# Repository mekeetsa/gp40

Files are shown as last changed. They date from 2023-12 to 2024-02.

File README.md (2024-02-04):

# Galaksija 40th Anniversary Tribute

This Galaksija Plus mod is based on PVV's clone from 2017
with the following modifications:

- USB HID keyboard/mouse/gamepad interface using RPI Pico
- a keyboard (optional) stackable either on the upper or the bottom side
- proper composite video output (no need to reduce the power in voltage)
- added an optional bus contention remover
- address decoder with ATF16V8B or g16v8s equivalent
  which provides a configurable MEMRQ map with 1 kB granularity
- improved SD hardware (SD now runs on the CPU clock)
- SD DOS version 8.12
- integrated micro SD socket with 3.3V PS and LVTTL level shifters
- integrated audio interface
- two I/O ports connected to the audio interface
- NMI reset circuit
- hybrid TH/SMD PCB (SMD discrete components on the bottom side)
- board dimensions 100 mm x 190 mm

## Specifications

- Z80A CPU at 3.072 MHz, 32 kB ROM (16k used), 32 kB static RAM
- Text mode 32x16 characters, monochrome
- Graphics mode: 256x208 pixels
- Storage: cassette tape (280 or 1200 bit/s) 
  MicroSD card (up to 4 GB) with SDOS
- Sound: 3 channels + white noise provided by AY-3-8910 or YM2149F
- I/O ports: two 8-bit parallel ports
- USB HID keyboard/mouse interface (as add-on)
- Power consumption: less than 250 mA at 5V 

## Firmware

- `GP40_U11_ROM.bin`, ROM 1-4, fits EPROM 27C128-27C512
- `GP40_U5_CHRGEN.bin`, character generator, fits EPROM 27C64-27C512
- `GP40_U2.jed`, address decoder, fits g16v8s
- `GP40_U40.jed`, SD interface, fits g16v8ms
- `GP40_U2.lgc` and `GP40_U40.lgc`, test vectors for XGecu Pro programmers

## Hardware memory map

```
  $0000...$0FFF  ROM A or 1: 4 kB (bootstrap and BASIC)
  $1000...$1FFF  ROM B or 2: 4 kB (math functions, etc.)
  $2000...$27FF  Keyboard and latch
  $2800...$BFFF  RAM: 30 kB ($2800...$2BFF Video RAM)
  $C000...$C7FF  RAM: 2 kB (used by SDOS)
  $C800...$CFFF  SD HWM PVV interface: 2 kB
  $D000...$DFFF  Unused, 4 kB (routed to CS on the expansion bus)
  $E000...$EFFF  ROM 3: 4 KB (Galaksija Plus, graphics)
  $F000...$FFFF  ROM 4: 4 KB (SD DOS)
```

## Credits
 
- Voja Antonic: Galaksija (1983)
- Nenad Dunjic and Milan Tadic: Galaksija Plus mod (1985)
- PVV and Fifan: Galaksija Plus clone with SD card (2016)
  http://www.nedopc.org/forum/viewtopic.php?p=87313
- Goran Stankovic (YT2FSG):  Retro Computers web page
  https://www.qsl.net/yt2fsg/galaksija/galaksija_clone.html
- Retro Bertie (@MacBerti28): YouTube guide
 
## Soldering sequence
 
  1. start with the SMD components on the bottom side
     (the SMD components are 0805+ and easy to solder)
  2. solder the SMD components on the top side
  3. solder the IC sockets
  4. solder the rest of the TH components

# Subprojects

## LTspice_composite_video

Simulations for adjustment of the composite video impedance maching
and amplification (i.e. output signal levels).

## LTspice_SD_interface

Simulations for the optimized SD interface.

## SDOS_V8C_GP40

Contains SD DOS version v8.12 that supports the optimized SD interface 
(with one g16v8ms and one 74HCT299).

## Add-ons

- Pico_USB_HID, USB HID (keyboard/mouse/gamepad) interface
- PS2_KBD, PS/2 interface
- Keyboard MX Cherry keyboard

## PCB Images

PCB release R1C and R1D

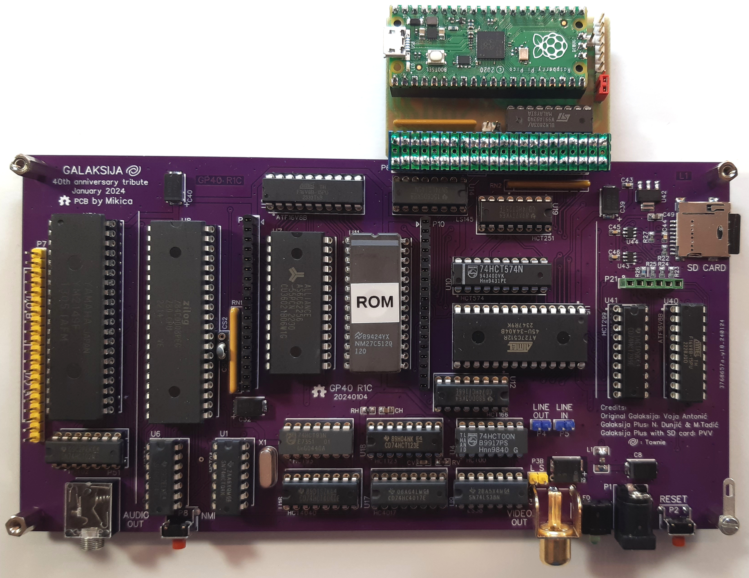
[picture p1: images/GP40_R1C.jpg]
GP40 R1C


PCB release R1A

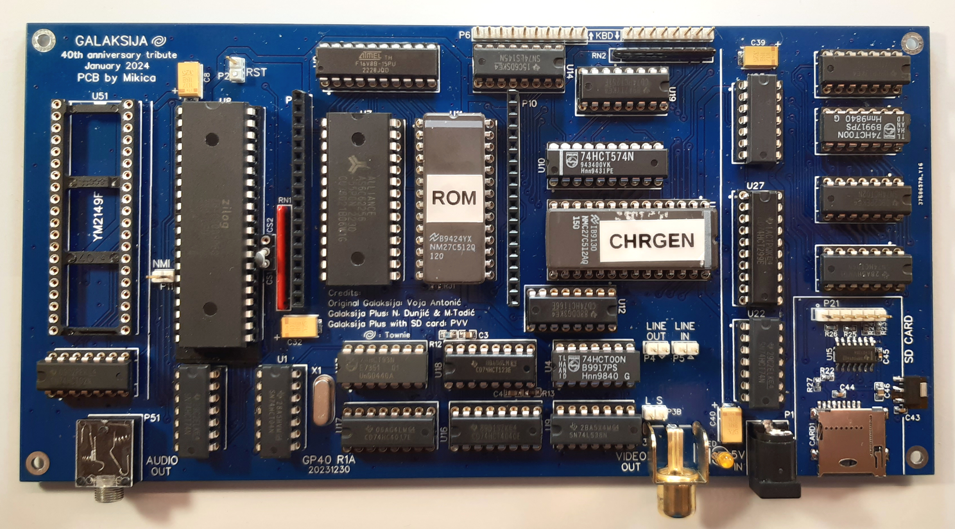
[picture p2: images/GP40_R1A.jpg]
GP40 R1A


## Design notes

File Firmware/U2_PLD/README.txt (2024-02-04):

Install WinCUPL from:

    https://www.microchip.com/en-us/products/fpgas-and-plds/spld-cplds/pld-design-resources

into:

    C:\Wincupl

The graphical interface does not work on Win 10. Use cupl.exe instead or wine under Linux.

Related Mnemonics:  g16v8, g16v8as, g16v8ma, g16v8ms, g16v8s

       Registered  Complex   Simple    Auto Mode Select
CUPL   G16V8MS     G16V8MA   G16V8AS   G16V8

In registered mode pin 1 and pin 11 are permanently configured
as clock and output enable, respectively. These pins cannot be configured
as dedicated inputs in the registered mode.

In complex mode pin 1 and pin 11 become dedicated inputs and
use the feedback paths of pin 19 and pin 12 respectively. Because
of this feedback path usage, pin 19 and pin 12 do not have the
feedback option in this mode.

In simple mode all feedback paths of the output pins are routed
via the adjacent pins. In doing so, the two inner most pins (pins
15 and 16) will not have the feedback option as these pins are
always configured as dedicated combinatorial output.

            ______________
           |    GP_U2     |
 !MREQ x---|1           20|---x Vcc  
   A15 x---|2           19|---x A14R 
   A14 x---|3           18|---x A7R  
    A7 x---|4           17|---x !RAM 
   A13 x---|5           16|---x A13R 
       x---|6           15|---x !CSE 
   A11 x---|7           14|---x !KEY 
   A12 x---|8           13|---x !ROM 
   D13 x---|9           12|---x !CSSD
   GND x---|10          11|---x      
           |______________|
           
=============================================
      !                             !        
      M                     ! ! ! ! C  A A   
      R  A A A  A A    D A  R R C K S  1 1   
      E  1 1 1  1 1  A 1 7  O A S E S  4 3   
      Q  5 4 3  2 1  7 3 R  M M E Y D  R R      
=============================================
0001: X  X X X  X X  X X X  X X X X X  X X
0002: X  X X X  X X  0 1 L  X X X X X  X X
0003: X  X X X  X X  0 0 H  X X X X X  X X
0004: X  X X X  X X  1 0 H  X X X X X  X X
0005: X  X X X  X X  1 1 H  X X X X X  X X
0006: 1  X X X  X X  X X X  H H H H H  X X
0007: 0  0 0 0  X X  X X X  L H H H H  L L
0008: 0  0 0 1  0 0  X X X  H H H L H  L H
0009: 0  0 0 1  0 1  X X X  H L H H H  L H
0010: 0  0 0 1  1 0  X X X  H L H H H  L H
0011: 0  0 0 1  1 1  X X X  H L H H H  L H
0012: 0  0 1 0  X X  X X X  H L H H H  H L
0013: 0  0 1 1  X X  X X X  H L H H H  H H
0014: 0  1 0 0  X X  X X X  H L H H H  L L
0015: 0  1 0 1  X X  X X X  H H L H H  L H
0016: 0  1 1 0  0 0  X X X  H L H H H  L H
0017: 0  1 1 0  0 1  X X X  H H H H L  L H
0018: 0  1 1 0  1 0  X X X  H H H H L  L H
0019: 0  1 1 0  1 1  X X X  H H H H L  L H
0020: 0  1 1 1  X X  X X X  L H H H H  H H

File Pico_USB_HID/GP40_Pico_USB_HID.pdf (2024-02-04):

A | A
B | B
C | C
D | D

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
### TITLE:

GALAKSIJA Pico USB HID | REV: | 1.0
Date: | 2024-01-24
Sheet: | 1/1
Drawn By: | mikica
Company: | Umuntu ngumuntu ngabuntu

+3V3

GND | GND GND

GND

GND | GND

GND

GND

RX
TX

VBUS

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
GP0-GP6 are configured as inputs. GP7-GP15 are configured as outputs.

KCs are connected to LS145. KRs are connected to LS251.

column scan

A USB HID is connected through an OTG USB cable.
The power to the HID is through J1.
Supported HIDs are keyboards and mice.

Interfacing between 3V3 and 5V TTL is done using open collectors. Adding the pull-ups will decrease speed-up low-high O.C. recovery.

RP2040 has two cores where TinyUSB runs on the first core.

The second core is dedicated to column scan / row response.
It runs a loop where the KC bits are mapped to the KR bits.
The KC/KR matrix occupies 128 bytes of memory.
The response time is max 200 ns with RP2040 running at 125 MHz. The RP2040 can be overclocked up to 400 MHz (which is not needed).

Debugging is done using SWD. Wiring setup:
- connect J2 (SWD) and J3 (UART0) to Pico probe
- if standalone, connect power to J1 pins 1-2
- if connected to Galaksija, install a jumper between J1 pins 2-3

ULN2803A

U2

1IN 1
2IN 2
3IN 3
4IN 4
5IN 5
6IN 6
7IN 7
8IN 8
GND 9 | COM 10 OUT8 11 OUT7 12 OUT6 13 OUT5 14 OUT4 15 OUT3 16 OUT2 17 OUT1 18

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
column scan

row response

2k-10k

RN1

+3V3

+3V3

HDR_1x3

J2

3

1
2

0.1u

C1
0.1u

C2

+5V

row response

GND HDR_1x3

J1
3

1

2

HDR_1x3

J3
3

1

2

GND

SWDIO

SWCLK
GND

RUN
HDR_1x1

J4
1

Note that the power on the Pico's USB connector is sourced out.

J1 usage: Normally jumper between pins 2-3 (+5V to VBUS).
If standalone (debugging), connect an external cable to pins 1-2.

column scan

VBUS

0.1u

C3

CPU_RESET
BSS138

Q1

CPU_RESET

10k

R1

CTRL-ALT-DELETE
sets \RESET to low.

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
2k-10kR2
2k-10kR3
2k-10kR4
2k-10kR5
2k-10kR6
2k-10kR7
2k-10kR8
2k-10kR9
2k-10kR10 | \RESET

Optional pull-ups 2k-10k
(to decrease turn-on/off delay time of O.C.)

\RESET

Keyboard

P6
GND 1

KC6 2
KC5 3
KC4 4
KC3 5
KC2 6
KC1 7

KC0 8 KR0 14 KR1 15 KR2 16 KR3 17 KR4 18 KR5 19 KR6 20 KR7 21

VCC 10 GND 9 GND 11 | \RST 12

N.C. 13

\RESET

RASPBERRY PI PICO
GP0 1

U1

GP1 2

GP2 4
GP3 5
GP4 6
GP5 7

GP6 9
GP7 10
GP8 11
GP9 12

GP10 14
GP11 15
GP12 16
GP13 17

GP14 19

GP15 20 | GP16 21 GP17 22

GP18 24 GP19 25 GP20 26 GP21 27

GP22 29 RUN 30 GP26 31 GP27 32

GP28 34

GND 3

GND 8

GND 13

GND 18 | GND 23

GND 28

GND 33

GND 38
ADC_VREF 35 3V3_OUT 36 3V3_EN 37

VSYS 39 VBUS 40

PWM 3

PWM 6

PWM 5

PWM 2

PWM 1

PWM 0PWM 7

PWM 6

PWM 5

PWM 4

PWM 3

PWM 2

PWM 1

# PWM 0 SWCLK 41

## GND 42

## SWDIO 43

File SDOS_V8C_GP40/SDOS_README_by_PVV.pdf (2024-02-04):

SD Card and SDOS for 8-bit Computers Author: PVV (Vitaly V. Popov, Rostov-on-Don)

Source: https://zx-pk.ru/threads/29892-sd-karta-i-sdos-dlya-8i-bitnykh-pk.html
Author: https://www.qrz.ru/db/RX6LEJ

http://www.nedopc.org/forum/viewtopic.php?id=6181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 (version 8.9J, Jupiter ACE, latest found)

The most recent version found: v8.C from 11.03.2020, 23:15 https://zx-pk.ru/attachment.php?attachmentid=71773&d=1583957695

I have a desire to organize and compile all the information about the SDOS system in one place. Honestly, I did not anticipate that SDOS would grow to its current scale, and now I sometimes face difficulty finding information about a specific build.

What is SDOS?

SDOS is a compact console shell that allows reading and executing files from an SD card formatted in FAT16. It can also write data back to the card from the computer's RAM. This makes it very easy to transfer files between 'big' PCs and our retrocomputers. The codebase of SDOS is based on the code from the respected b2m (http://bashkiria-2m.narod.ru), which I framed with additional functionality and capabilities. The system code is designed to be easily adaptable to any PC and any hardware interface and storage medium (it doesn't necessarily have to be an SD card; it can be an HDD).

SDOS properties:

- The code itself occupies from 2 to 2.5 KB (can be located in both ROM and RAM), and an additional 2 KB of RAM is required to work with FAT16.
- Has been compiled and tested at least in the emu emulator, and in some cases, in real life on the following PCs: Specialist std (real) and MX2 (real), RK-86 (real), Apogee, Partner-01, Galaksija (real), Orion (real), TRS-80 (real), YUT-88.
- Supports three basic SD hardware interfaces: HWM_PVV, msx, n8vem, and their derived variants.
- Supports SD and SDHC cards, i.e., cards larger than 4 GB.

Supports the following basic directives:

- CD DirectoryName
change to the directory with the specified name;
- DIR
display the list of files and directories;
- FileName.RKX
(RKS for std, RKR for RK-86, GTP for Galaksija, RKO for Orion, CAS for TRS-80) -execute the file; the extension can be omitted, and autocompletion will occur;
- R FileName.Extension, Address, Size
read the file without executing it, starting from the specified memory address and reading the specified number of bytes.

Example: R TEST.BIN,0ACD,5FE0 - reads the TEST.BIN file into memory starting from address 0x0ACD and ending at address 0x0ACD+0x5FE0=0x6AAD. There is no check for the actual length of the file and the requested read size, so you can request to read more than the file's size, and the behavior is undefined.

- W FileName.Extension, Address, Size
write data from memory to the file, starting from the specified address in memory and writing the specified number of bytes.

Example: W TEST.BIN,0ACD,5FE0 - writes to the TEST.BIN file from memory starting from address 0x0ACD and ending at address 0x0ACD+0x5FE0=0x6AAD. There is no check for the actual length of the file and the requested write size, so you can request to write more than the file's size, and the behavior is undefined. It is not possible to write more than the existing file size. If you write less data than the file size, the file size remains unchanged.

- X
switch to the monitor from which SDOS was launched;
- I
initiate card reinitialization.

Only for Galaksija:

- WB FileName.Extension
write BASIC program to the SD file in GTP format.

Only for SpecialistMX:

- L FileName.Extension
read the file in RKX format from SD to MX RAM disk; example: L TEST.BIN - reads the TEST.BIN file into memory starting from address 0x0000 and ending at its length address, creates a file TEST.BIN on the RAM disk with a start address and size taken from the first 4 bytes of the file on the card, assuming that the file name in the header was absent (0xE6 in the 5th byte). Or: L TEST.BIN - reads the TEST.BIN file into memory starting from address 0x0000 and ending at its length address, creates a file TEST_MX.HEX on the RAM disk with the start address and size read from the first 4 bytes of the file on the card, and the file name in the header is TEST_MX.HEX.
- S FileNameOnRAMDisk.Extension, FileNameOnSD.Extension
write the file data from RAM disk to SD in RKX format; example: S TEST.BIN - reads the TEST.BIN file from RAM disk into memory starting from address 0x0000 and ending at its length address, then writes it to the SD card in the existing file with the same name TEST.BIN, the size remains unchanged, RKX format! Or: S TEST.BIN,TEST_MX.HEX -reads the TEST_MX.HEX file into memory starting from address 0x0000 and ending at its length address, then writes it to the SD card in the existing file with the name TEST.BIN.

Only for Orion:

- L FileName.Extension
read the file in RKO format from SD to RAM disk; example: L TEST$.RKO - reads the

TEST$.RKO file into memory starting from address 0x0000 and ending at its length address, creates a file TEST$ on the RAM disk with the name, start address, and size taken from the RKO file header on the card.

- S FileNameOnRAMDisk, FileNameOnSD.Extension
write the file data from RAM disk to SD in RKO format; example: S TEST$,TEST1$.BIN -reads the TEST$ file from RAM disk into memory starting from address 0x0000 and ending at its length address, then writes it to the SD card in the existing file with the name TEST1$.BIN, the size remains unchanged, RKO format!

When listing the directory with DIR, the name, file extension, and size of the file are printed (so that you can use R and W directives), and for directories, DIR is written in the file size field.

When starting a file, the start and end addresses to which the file will be read from the card are written.

Pressing any key (or space) during DIR output pauses the file list output.

For SpecialistMX2, the ability to run not only RKX files but also RKS is implemented. To do this, in the same directory where the RKS file is located, you need to place the M2_C000.MON monitor file (taken from the Vinxru project). In addition, there is the possibility to load arbitrary monitors.

And now a lot of links, mentioning SDOS and SD interface.

It all started with this thread about Specialist with the HWM interface, and back then, I thought it would end there, but it didn't. The first attempt to organize information about SDOS within the framework of Specialist.

Version for RK-86 with HWM_PVV interface, then with RK86_WW55_SD_HWM_PVV interface, then Apogee with the original card connection option, an analog of the SD_n8vem interface. In these variants, the SD card is connected together with the ROM disk, without excluding it! Partner-01.

Version for Galaksija with HWM_PVV interface and with SD_n8vem interface.
Practical implementation in this thread.

YUT-88 with SD_n8vem interface.
Orion.
TRS-80.

Interface schematics:

HWM_PVV on IR8 and IR9 or on ports VV55. HWM_PVV on IR24 or here or here. HWM_PVV on IR13.

SD_n8vem or here or here or here.

I haven't tested SD_msx in real life, only in emulation, but initially, b2m's code was implemented to work specifically with this interface, and it was used in real life on PLD.

I want to add one more point. According to the specification, when initializing the SD card, you need to use an SD_CLK clock frequency not exceeding 400 kHz, and after initialization, switch to a higher frequency. But as practice has shown, modern cards easily initialize and work at a frequency of 2-4 MHz, allowing you to dispense with the clock speed switch. Speed switching is only supported in the HWM PLD interface and in the first version of the HWM_PVV interface on discrete components.

…

The source code for SDOS is open, and it can be downloaded from the link above.

SDOS is written in i8080 mnemonics (actually i8085) and runs on Z80 without any problems.

Each time I added any functionality or new platforms (PCs), I increased version and subversion numbers.

The current version is 8.9, but practically, it's 8.6, since 8.7 - 8.9 are just builds for different platforms with subvariants of the SD interface. At this stage, I realized that it shouldn't be like this; the end-user should build SDOS according to their requirements, and it shouldn't affect the system version.

Accordingly, I want to explain how SDOS is assembled, configured, or ported to another platform.

First, you need to determine the placement in the address space of the target platform. You need to decide where both the code of SDOS itself and its service area 2048-256=1792 bytes will be located, and at which addresses. You need to choose addresses that are not used by most programs for the best part. Here, you need to choose the optimal compromise. If the target platform has an external ROM disk, it is logical to place SDOS there and rewrite it into RAM by standard means during operation. (When porting to a new platform, you can choose almost any available addresses at the initial stage, and only at the final stage, determine the optimal memory placement). If there is free space in the address space of the target platform where you can place ROM (for example, Specialist and Galaxia), then SDOS is placed in such an area, and it works immediately from ROM. You just need to choose an available area for the service region.

Second, it overlaps with the first, which is choosing addresses for the ports of the SD interface. Two addresses are needed, which can be either addresses in the memory space or addresses in IO ports. For platforms with an external ROM disk, the choice may be simplified. There are two connection options in the links above. Otherwise, you need to search for options and compromises again.

Third, choose the SD interface variant. HWM_PVV is the fastest, and, in addition, its software support is the most compact, which is quite noticeable against the background of the compact
SDOS (remember ~2KB total!). 7 bodies of the 555 series. MSX is slower, and software support adds +150 bytes to the code, and in terms of the number of cases, it is approximately like the previous option. Therefore, I don't particularly consider it. N8VEM is the slowest, +250 bytes to the code, but it is very simple to implement, and therefore, it has the right to be considered. For our retro PCs, even the speed of N8VEM is not so bad because most files have a small size, which is not critical and still better than just a cassette recorder. Any subvariants of these interfaces, for example, connected via VV5, will be slightly slower and slightly inflate the program code on the whole.

At this stage, for existing platform variants, it is enough to correctly define the necessary capabilities in the defines and run the assembly with a bat file.

If you need to port SDOS to a new platform, then some research is needed here. In the defs.inc file, you need to make a section with a new platform, in which you need to define such functions (an example from RK-86):

```assembly
GETC EQU 0F803H ; Wait for a character from the keyboard
PUTC EQU 0F809H ; Output one character to the screen PRINT EQU 0F818H ; Output a string to the screen
PRHEX EQU 0F815H ; Output a number in HEX format
IfKeyPress EQU 0F81BH ; Non-hanging keyboard input check
```

You can see the input and output parameters of these functions, for example, here. The main ones are the first two, as PRINT is made from PUTC, PRHEX as an option, is already in the SDOS code and uses PUTC, and IfKeyPress can be commented out and not used (there will be no function to pause the file list output by pressing any key during DIR, forgot to mention this feature in the first message). GETC and PUTC are somehow implemented on the target platform, so you need to adjust their call format to the required SDOS (this was done when porting to Galaxia and TRS-80).

Here are the defines in the defs.inc file and what they mean (the presence of a semicolon ';' at the beginning of the line indicates the exclusion of this define, and its absence indicates inclusion):

```assembly
#define SDOS_VER "SDOS_V8.9N" ; In v8.9, moved the greeting text of SDOS to this define

#define SD_DBG_PRINT0 ; Also in v8.9, split one define SD_DBG_PRINT into three for #define SD_DBG_PRINT1 ; more flexible adjustment of the SDOS size, which is crucial when building compact code

#define SD_DBG_PRINT2 ; for placement in 2KB ROM (all these prints 'consume' up to 100 bytes of code).

;#define SD_HWM_PVV - this group of 8 defines determines the type of SD interface for assembly, corresponding to HWM_PVV
;#define SD_msx - MSX
;#define SD_n8vem - N8VEM
;#define RK86_WW55_SD_HWM_PVV - this is the HWM_PVV variant connected to VV55 ports, tested on a real RK-86, hence the name
;#define RK86_WW55_SD_n8vem ; APOGEE and RK86 memmap - this is the N8VEM variant connected to VV55 ports, where VV55 is placed in the address space, not in the ports, assembled but not yet tested on RK86
#define STD_WW55_SD_n8vem ; Specialist - this is a complete copy (!?!) of the RK86_WW55_SD_n8vem variant, assembled but not tested on a real system, for the Specialist (Std) - in the next version, I will combine it into one define WW55_ADDR_SD_n8vem

;#define UT88_WW55_SD_n8vem ; ports IN - OUT - this is the N8VEM variant connected to VV55 ports, where VV55 is placed in IO ports, assembled but not yet tested on UT-88 - in the next version, I will rename the define to WW55_IO_SD_n8vem
;#define GAL_AY_SD_n8vem - this is the N8VEM variant connected to AY3-8910(YM2149F) ports, where AY is placed in IO ports, tested on a real Galaxia - in the next version, I will rename the define to AY_IO_SD_n8vem

;#define FAT12_ON - enabling FAT12 support on the card, relevant for cards or partitions less than 32MB, usually turned off for code size savings

#define FAT16_ON - enabling FAT16 support on the card, the main one

#define RWR - enabling write support to the card, takes up 200-300 bytes

;#define UT88- this group of 8 defines determines the type of platform for which SDOS is assembled. UT-88
;#define APOGEE | - Apogee
;#define RK86 | - RK-86
#define STD - Specialist

;#define MX2 - SpecialistMX2 - relevant for the original SD_HWM_PVV, where the bit signaling 'BUSY' of the SPI state machine is involved (in all 'my' variations of this interface, I dropped this bit because knowing the CPU speed with the SD interface, you can adjust the required delay with NOPs, literally from 1 to 3 pieces)
;#define GAL - Galaxia
;#define ORION | - Orion
;#define TRS80 | - TRS80
```

Here's a translation of the section about platform-specific defines and the list of source code files:

```assembly
;================================================= =========
#ifdef RK86

GETC EQU 0F803H - wait for a character from the keyboard
PUTC EQU 0F809H - output one character to the screen
PRINT EQU 0F818H - output a string to the screen
PRHEX EQU 0F815H - output a number in HEX format
IfKeyPress EQU 0F81BH - keyboard input check, non-blocking
SD_DATA_PORT EQU 0d000H - address where the SD interface and its data port are located SD_CONF_PORT EQU SD_DATA_PORT+1 - address where the SD interface and its configuration port are located
SD_DATA_PORT_WW55 EQU 0a000H - address where the SD interface and its VV55 port are located for SD variants with VV55
#define SD_ROM - relevant only for RK-86; if not selected, a jmp F800h is placed at address F000 #ifdef SD_ROM

START_ADDR EQU 06000H - starting address for placing the SDOS code (read from RK's ROMdisk)
#else

START_ADDR EQU 0f000H - starting address for placing the SDOS code if it is stored in ROM #endif
BUF EQU 06900h - starting address for placing the service area (buffers for working with FAT), takes up 2048-256=1792 bytes
#endif

;================================================= =========

The source codes of SDOS are in several files:

- defs.inc - contains all the defines described earlier
- dos_rk.asm - the main file, in which the implementation of the entire interface for interacting with SDOS and the user is located

There are six files for each of the supported platforms, implementing the file reading and execution function, plus specific features for a particular platform (working with RAMdisk in SpecialistMX2 or Orion, writing basic files in Galaxia).

When building, the file of the platform defined in the defs.inc file is used. The file is included in the dos_rk.asm file.

When adding a new platform, you will need to add such a file.
- dos_gal_RUNF.inc
- dos_mx_RUNF.inc
- dos_orion_RUNF.inc
- dos_rk_RUNF.inc
- dos_std_RUNF.inc
- dos_trs_RUNF.inc
- sd_proc.inc - contains all functions for working with the SD card itself
- fs_proc.inc - contains all functions for working with the FAT12 and FAT16 file systems.

In addition to the above files, the SDOS archive also includes:

- asm_std.cmd - a text BAT file that describes the SDOS build options; you need to run it for the build after configuring all the defines.
- ReadMe.txt - a text file with a very brief description of SDOS capabilities
- TASM.EXE - this is the assembler used for building
- TASM85.TAB - this is an assembler auxiliary file

The entire build process for the user consists of configuring the defines in the defs.inc file and executing asm_std.cmd. The result will be the required SDOS.BIN file.

Here is a translation of the configuration details for the emulator:

There is always a desire to check what has been achieved, and in this case, the emulator "emu" becomes a tremendous help. This emulator supports all three types of SD interfaces and their variations. You need to search the directory for configuration files with such content and configure as needed, following a similar pattern:

For HWM_PVV:
mm2: MemMap2 {
map[00] = sdcard.data8
map[01] = 40
}

For msx:
mm2: MemMap2 {
map[00] = sdcard.ss
map[01] = sdcard.data
}

For n8vem, on the VV55 ports: miso: Register {
read[0] = sdcard.miso
read[1] = sdcard.miso
read[2] = sdcard.miso
read[3] = sdcard.miso
read[4] = sdcard.miso
read[5] = sdcard.miso
read[6] = sdcard.miso
read[7] = sdcard.miso
}

appmx: MemMap2 {
map[0] = romdisk.data
map[1] = miso
}

app: K580ww55 {
portA = appmx
portB = romdisk.lsb
portC = romdisk.msb
portC[0] = sdcard.mosi
portC[5] = sdcard.sclk
portC[E] = sdcard.ss
portC[7] = appmx.offset
}

This configuration is used to emulate the SD interfaces (HWM_PVV, msx, and n8vem) in the "emu" emulator. You may need to adapt these configurations based on your specific needs or the specifics of the emulator you are using.

## SD карта и SDOS для 8и битных ПК

У меня возникло желание упорядочить и собрать в одном месте всю информацию о системе SDOS. Честно говоря, я не предполагал, что SDOS разрастется до текущих маштабов, и сейчас сам иногда испытываю сложность в поиске информации о том или ином варианте сборки.

Что же такое SDOS?

SDOS это компактная консольная оболочка позволяющая читать, запускать на исполнение файлы с SD карты, отформатированной в FAT16, и записывать обратно на карту данные из ОЗУ компьютера. Это позволяет очень просто переносить файлы с 'больших' ПК в наши ретрокомпьютеры и обратно. В основе кода SDOS взят код уважаемого b2m, который я обрамил дополнительным функционалом и возможностями.

Код системы построен таким образом, что его очень просто можно адаптировать к любому ПК и к любому варианту аппаратного интерфейса и носителя (те, вообще говоря, это не обязательно должна быть SD карта, а может быть и HDD). (https://zx-pk.ru/threads/29892-sd-karta-i-sdos-dlya-8i-bitnykh-pk.html?p=1050685&viewfull=1)

На данный момент SDOS:

- код самой SDOS занимает от 2 до 2.5КБ (может размещаться как в ПЗУ так и в ОЗУ), плюс для работы с FAT16 нужно еще 2КБ ОЗУ.
- собиралась и проверялась как минимум в эмуляторе emu, а в некоторых случаях и в реале на следующих ПК: Специалист std(реал) и MX2(реал), RK-86(реал), Апогей, Партнер-01, Galaksija(реал), Orion(реал), TRS-80(реал), ЮТ-88.
- поддерживает три базовых аппаратных интерфейса SD: HWM_PVV, msx, n8vem, и их производные варианты.
- поддерживает SD и SDHC карты, те карты с размером больше 4ГБ.
- поддерживает следующие базовые директивы:
- CD ИМЯкаталога - перейти в каталог с указанным именем;
- DIR - вывести список файлов и каталогов;
- ИМЯфайла.RKX(RKS для std, RKR для RK-86, GTP для Галаксии, RKO - Орион, CAS - TRS-80 ) запустить файл, при этом расширение можно не набирать, будет произведена автоподстановка;
- R ИМЯфайла.РАСШИРЕНИЕфайла,А ДРЕСкуда,СКОЛЬКОбайт - прочитать не запуская файл, начиная с указанного адреса в памяти и сколько байт пример: R TEST.BIN,0ACD,5FE0 - читает файл TEST.BIN в память начиная с адреса 0х0ACD и до адреса 0х0ACD+0х5FE0=0х6AAD. Ограничение -нет проверки на фактическую длину файла и запрошенную на чтение, те можно запросить прочитать больше чем размер файла, поведение не определено
- W ИМЯфайла.РАСШИРЕНИЕфайла,А ДРЕСоткуда,СКОЛЬКОбайт - записать в файл данные из памяти, начиная с указанного адреса в памяти и сколько байт пример: W TEST.BIN,0ACD,5FE0 -пишет в файл TEST.BIN из памяти начиная с адреса 0х0ACD и до адреса 0х0ACD+0х5FE0=0х6AAD. Ограничение - нет проверки на фактическую длину файла и запрошенную на запись, те можно запросить записать больше чем размер файла, поведение не определено. Записать больше чем существующий размер файла нельзя, если записать данных меньше чем размер файла, то размер файла не меняется и остается прежний
- X - перейти в монитор, из которого был запущен SDOS;

- I - запуск повторной инициализации карты;

только Galaksija:

- WB ИМЯфайла.РАСШИРЕНИЕ - запись BASIC программы в файл на SD в формате GTP;

только СпецециалистМХ:

- L ИМЯфайла.РАСШИРЕНИЕфайла - прочитать данные файла формата RKX с SD в RAM диск МХа; пример: L TEST.BIN - читает файл TEST.BIN в память начиная с адреса 0х0000 и до адреса его длины, создает в RAM диске файл TEST.BIN с стартовым адресом и размером взятыми из 4х первых байт файла на карте, при том, что имя файла в хеадере отсутствовало (в 5м байте 0хЕ6).
Или: L TEST.BIN - читает файл TEST.BIN в память начиная с адреса 0х0000 и до адреса его длины, создает в RAM диске файл TEST_MX.HEX, с стартовым адресом и размером считанные из 4х первых байт файла на карте, и именем файла в хеадере TEST_MX.HEX.
- S ИМЯфайлаНаRAMдиске.РАСШИРЕН ИЕ,ИМЯфайлаНаSD.РАСШИРЕНИЕ - записать данные файла из RAM диска МХа на SD в формате RKX; пример: S TEST.BIN - читает файл TEST.BIN из RAM диска в память начиная с адреса 0х0000 и до адреса его длины, после записывает его на SD карту в существующий файл с таким же именем TEST.BIN, размер не изменяется, формат RKX! Или: S TEST.BIN,TEST_MX.HEX - читает файл TEST_MX.HEX в память начиная с адреса 0х0000 и до адреса его длины, после записывает его на SD карту в существующий файл с именем TEST.BIN.

только Orion:

- L ИМЯфайла.РАСШИРЕНИЕфайла - прочитать данные файла формата RKO с SD в RAM диск; пример: L TEST$.RKO - читает файл TEST$.RKO в память начиная с адреса 0х0000 и до адреса его длины, создает в RAM диске файл TEST$ с именем, стартовым адресом и размером взятыми из хеадера RKO файла на карте.
- S ИМЯфайлаНаRAMдиске,ИМЯфайла НаSD.РАСШИРЕНИЕ - записать данные файла из RAM диска на SD в формате RKO. пример: S TEST$,TEST1$.BIN -читает файл TEST$ из RAM диска в память начиная с адреса 0х0000 и до адреса его длины, после записывает его на SD карту в существующий файл с таким же именем TEST1$.BIN, размер не изменяется, формат RKO!.

При выводе каталога по DIR печатается имя, расширение файла и его размер(что бы можно было использовать директивы R и W), а на директории пишется DIR в поле размера файла.

При запуске файла пишется стартовый и конечный адреса куда будет считан файл с карты.

Нажатие любой клавиши (пробела) при выводе по DIR приостанавливает вывода списка файлов.

Для СпециалистМХ2 сделана возможность запускать не только файлы с расширением RKX, но и RKS, для чего в том же каталоге, где находится RKS файл нужно поместить файл монитора M2_C000.MON (https://zx-pk.ru/threads/27418-rabota-s-sd-kontrollerom-na-spetsialiste_mkh2.html?p=993336&viewfull=1) (взят из проекта Vinxru). Кроме того, есть возможность загружать произвольные мониторы. (https://zx-pk.ru/threads/27418-rabota-s-sd-kontrollerom-na-spetsialiste_mkh2.html?p=955214&viewfull=1)

И теперь масса ссылок, с упоминанием SDOS и SD интерфейса.

Началось все с этой (http://www.nedopc.org/forum/viewtopic.php?f=90&t=11446) темы по Специалисту с интерфейсом HWM, (http://www.spetsialist-mx.ru/index32.html) и тогда я думал, что на этом все закончится, да не тут то было.
Первая (http://www.nedopc.org/forum/viewtopic.php?f=90&t=17331) попытка упорядочить информацию по SDOS в рамках Специалиста.

Версия (http://www.nedopc.org/forum/viewtopic.php?f=93&t=16296#p132181) для РК-86 с интерфейсом HWM_PVV, и там же, дале с интерфейсом RK86_WW55_SD_HWM_PVV,
далее Апогей (http://www.nedopc.org/forum/viewtopic.php?f=93&t=16296&start=15#p145339) с оригинальным вариантом подключения карты, аналог интерфейса SD_n8vem. В этих

вариантах SD карта подключена совместно с ROM диском, не исключая его! Партнер-01 (https://zx-pk.ru/threads/29755-partner-01-01-modul-sd-karty.html?p=987692&viewfull=1#post987692) .

Версия для Галаксии (http://www.nedopc.org/forum/viewtopic.php?f=71&t=9407&start=225#p143285) с интерфейсом HWM_PVV и с интерфейсом SD_n8vem (http://www.nedopc.org/forum/viewtopic.php?f=71&t=9407&start=270#p145367) . Практическая реализация в этой (https://zx-pk.ru/threads/29446-galaksiya-(plyus)-sborka-i-nastrojka.html) теме.

Ют-88 (https://zx-pk.ru/threads/24628-yut-88-vneshnie-nakopiteli.html?p=974013&viewfull=1#post974013) с интерфейсом SD_n8vem.
Орион (https://zx-pk.ru/threads/28704-sd-karty-i-kontrollery-realizatsii-fat.html?p=953635&viewfull=1) .
TRS-80 (http://www.nedopc.org/forum/viewtopic.php?f=71&t=17688#p143514) .

Схемы интерфейсов:

HWM_PVV на ИР8 и ИР9 (http://www.nedopc.org/forum/viewtopic.php?f=90&t=11446&start=75#p134316) или на портах ВВ55 (http://www.nedopc.org/forum/viewtopic.php?f=93&t=16296&start=15#p134110) . HWM_PVV на ИР24 (http://www.nedopc.org/forum/viewtopic.php?f=90&t=11446&start=75#p134101) или здесь (https://zx-pk.ru/attachment.php?attachmentid=64558&d=1520701260) или здесь (https://zx-pk.ru/threads/29892-sd-karta-i-sdos-dlya-8i-bitnykh-pk.html?p=1020948&viewfull=1) HWM_PVV на ИР13 (http://www.nedopc.org/forum/viewtopic.php?f=71&t=9407&start=285#p148843)

SD_n8vem (http://www.nedopc.org/forum/viewtopic.php?f=93&t=16296&start=15#p145339) или здесь (http://www.nedopc.org/forum/viewtopic.php?f=71&t=9407&start=270#p145367) или здесь (https://zx-pk.ru/threads/28704-sd-karty-i-kontrollery-realizatsii-fat.html?p=946077&viewfull=1) или здесь (http://www.nedopc.org/forum/viewtopic.php?f=96&t=18820&start=45#p144089)

SD_msx (http://msx.hansotten.com/uploads/fyfiles/MMC_Drive.zip) я на реале не проверял, только в emu, но изначально код b2m был реализован для работы именно с этим интерфейсом и он использовался на реале в плис.

Хочу дополнить еще один момент. Согласно спецификации, при инициализации SD карты нужно использовать частоту тактирования SD_CLK не выше 400кГц, а по завершению инициализации переключаться на более высокую. Но как показала практика, современные карты спокойно инициализируются и работают на частоте 2-4МГц, что позволяет отказаться от переключателя скорости тактирования. Переключение скорости поддерживается только в интерфейсе на ПЛИС HWM и в первом варианте интерфейса HWM_PVV на дискретах.
Последний раз редактировалось PVV; 11.03.2020 в 23:17.

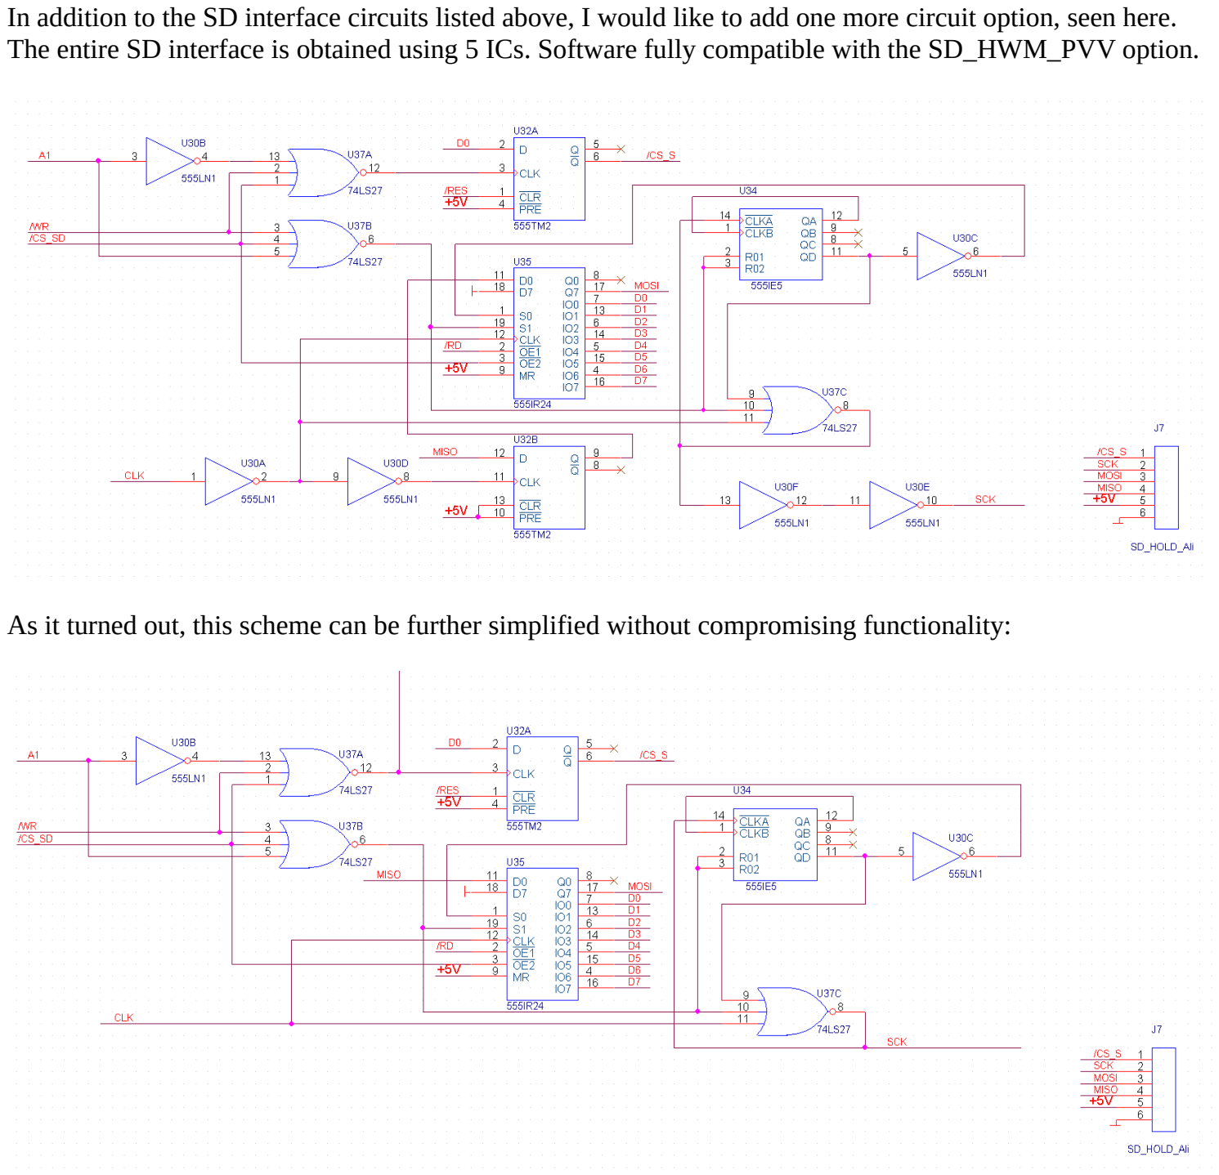
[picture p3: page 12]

In addition to the SD interface circuits listed above, I would like to add one more circuit option, seen here. The entire SD interface is obtained using 5 ICs. Software fully compatible with the SD_HWM_PVV option.

As it turned out, this scheme can be further simplified without compromising functionality:

Инструкция и памятка для себя по SDOS:
Текущая версия SDOS_v8C

поддерживаются ПК: Специалист std и MX, RK-86, Galaksija, Orion, TRS-80, JupiterACE поддерживает аппаратные интерфейсы SD: HWM_PVV, msx, n8vem

поддерживает следующие базовые директивы:
- CD ИМЯкаталога - перейти в каталог с указанным именем;
- DIR - вывести список файлов и каталогов;
- ИМЯфайла.RKX(RKS для std, RKR для RK-86 и GTP для Галаксии, RKO - Орион, CAS - TRS-80 )
запустить файл, при этом расширение можно не набирать, будет произведена автоподстановка;
- R ИМЯфайла.РАСШИРЕНИЕфайла,АДРЕСкуда,СКОЛЬКОбайт - прочитать не запуская файл, начиная с указанного адреса в памяти и сколько
байт (пример: R TEST.BIN,0ACD,5FE0 - читает файл TEST.BIN в память начиная с адреса 0х0ACD и до адреса 0х0ACD+0х5FE0=0х6AAD). Ограничение -нет проверки на фактическую длину файла и запрошенную на чтение, те можно запросить прочитать больше чем размер файла, поведение не определено;
- W ИМЯфайла.РАСШИРЕНИЕфайла,АДРЕСоткуда,СКОЛЬКОбайт - записать в файл данные из памяти, начиная с указанного адреса в памяти и сколько байт (пример: W TEST.BIN,0ACD,5FE0 - пишет в файл TEST.BIN из памяти начиная с адреса 0х0ACD и до адреса 0х0ACD+0х5FE0=0х6AAD). Ограничение - нет проверки на фактическую длину файла и запрошенную на запись, те можно запросить записать больше чем размер файла, поведение не определено. Записать больше чем существующий размер файла нельзя, если записать данных меньше чем размер файла, то размер файла не меняется и остается прежний;
- X - перейти в монитор, из которого был запущен SDOS;
- I - запуск повторной инициализации карты;

только Galaksija:
- WB ИМЯфайла.РАСШИРЕНИЕ - запись BASIC программы в файл на SD в формате GTP;

только СпецециалистМХ:
- L ИМЯфайла.РАСШИРЕНИЕфайла - прочитать данные файла формата RKX с SD в RAM диск МХа;
- S ИМЯфайлаНаRAMдиске.РАСШИРЕНИЕ,ИМЯфайлаНаSD.РАСШИРЕНИЕ - записать данные файла из RAM диска МХа на SD в формате RKX;

только Orion:
- L ИМЯфайла.РАСШИРЕНИЕфайла - прочитать данные файла формата RKO с SD в RAM диск;
- S ИМЯфайлаНаRAMдиске,ИМЯфайлаНаSD.РАСШИРЕНИЕ, - записать данные файла из RAM диска на SD в формате RKO.

При выводе каталога по DIR печатается имя, расширение файла и его
размер(что бы можно было использовать директивы R и W), а на директории
пишется DIR в поле размера файла.

При запуске файла пишется стартовый и конечный адреса куда будет считан
файл с карты.
добавлено 24.05.2017: | - для СпециалистМХ(2)
- L ИМЯфайла.РАСШИРЕНИЕфайла - прочитать данные файла формата RKX с SD в RAM диск МХа (пример: L TEST.BIN - читает файл TEST.BIN в память начиная
с адреса 0х0000 и до адреса его длины, создает в RAM диске файл TEST.BIN
с стартовым адресом и размером взятыми из 4х первых байт файла на карте,
при том, что имя файла в хеадере отсутствовало (в 5м байте 0хЕ6).
Или: L TEST.BIN - читает файл TEST.BIN в память начиная с адреса
0х0000 и до адреса его длины, создает в RAM диске файл TEST_MX.HEX,
с стартовым адресом и размером считанные из 4х первых байт файла на карте, и именем файла в хеадере TEST_MX.HEX).
- S ИМЯфайлаНаRAMдиске.РАСШИРЕНИЕ,ИМЯфайлаНаSD.РАСШИРЕНИЕ, ИМЯфайлаНаSD опциональный параметр,
указывается только для варианта файлов с одинаковыми именами на RAM диске но разными расширениями - записать данные файла из RAM диска МХа на SD в формате RKX (пример: S TEST.BIN -
читает файл TEST.BIN из RAM диска в память начиная с адреса 0х0000 и до адреса его длины, после записывает его на SD карту в существующий файл с таким же именем TEST.BIN, размер не изменяется, формат RKX!
Или: S TEST.BIN,TEST_MX.HEX - читает файл TEST_MX.HEX в память начиная с адреса 0х0000 и до
адреса его длины, после записывает его на SD карту в существующий файл с именем TEST.BIN).

14.02.2018 SDOS_v8
сделал поддержку SDHC карт, есть отладочный вывод с типом обнаруженной карты и информации
о наличии FAT16 на карте.
Добавил директиву I - запуск повторной инициализации карты.

21.02.2018 SDOS_V8.1
для Галаксии добавил директиву:
WB ИМЯфайла.РАСШИРЕНИЕ - запись BASIC программы в файл на SD в формате GTP.

01.03.2018 SDOS_V8.3
- L ИМЯфайла.РАСШИРЕНИЕфайла - прочитать данные файла формата RKO с SD в RAM диск Orion (пример: L TEST$.RKO - читает файл TEST$.RKO в память начиная
с адреса 0х0000 и до адреса его длины, создает в RAM диске файл TEST$
с именем, стартовым адресом и размером взятыми из хеадера RKO файла на карте.
- S ИМЯфайлаНаRAMдиске,ИМЯфайлаНаSD.РАСШИРЕНИЕ, - записать данные файла из RAM диска на SD в формате RKO (пример: S TEST$,TEST1$.BIN -читает файл TEST$ из RAM диска в память
начиная с адреса 0х0000 и до адреса его длины, после записывает его на SD карту в существующий файл с таким же именем TEST1$.BIN, размер не изменяется, формат RKO!).

05.03.2018 SDOS_V8.4
добавил поддержку TRS-80

01.06.2018 SDOS_V8.6
добавил чтение двух байт CRC после вычитки сектора, пакета данных в 512 байт

10.07.2018 SDOS_V8.7
добавил поддержку SD_WW55_n8vem

11.10.2019 SDOS_V8A
изменил размещение кода внутри самой SDOS и оптимизировал по размеру

04.03.2020 SDOS_V8C
первая попытка добавления IDE вместо SD на примере Ориона

{
формат заголовка файла RKX:
1) 2 байта -стартовый адрес;
2) 2 байта -конечный адрес (длина данных=конечный адрес-стартовый адрес);
3) опционально, 1+8+1+3=13 байт - признак автозапуска, имя и расширение файла в RAMFOS, между именем
и расширением ' ', автозапуск этого файла с его адреса загрузки 0 - нет, FF - да;
4) опционально, 1+8+1+3=13 байт -признак автозапуска, имя монитора с расширением, между именем и расширением '.', автозапуск имеет приоритет над 3), без 3) не имеет смысла;

5) опционально, 1+8+1+3=13 байт еще один монитор (как пункт 4) ), автозапуск имеет приоритет над 4);
6) 0хЕ6 - это 'маркер завершения' дескриптора RKX;
7) данные файла;
}

{
формат заголовка RKO:
8 байт имя
64 нулевых байт, потом 0E6h (синхробайты) 2 байта начало (обычно 0000)
2 байта конец (старший байт первый)
16 байт ORDOS-заголовок
(конец-начало-10h) данные
3 нулевых байта, потом 0E6h (синхробайты) 2 байта контрольная сумма
}

{
формат заголовка ORD:
0-7 - ИМЯ ФАЙЛА. МОЖЕТ СОДЕРЖАТЬ НЕ БОЛЕЕ 8 СИМВОЛОВ. ЕСЛИ ИМЯ СОДЕРЖИТ МЕНЬШЕ СИМВОЛОВ,
СВОБОДНЫЕ ЯЧЕЙКИ ЗАПОЛНЯЮТСЯ ПРОБЕЛАМИ.
8-9 - НАЧАЛЬНЫЙ АДРЕС РАЗМЕЩЕНИЯ ПРОГРАММЫ ПРИ СЧИТЫВАНИИ ЕЕ ИЗ ДИСКА В ОЗУ - АДРЕС "ПОСАДКИ".
А-В - РАЗМЕР ФАЙЛА. В ЭТОТ ПАРАМЕТР ОГЛАВЛЕНИЕ ФАЙЛА(16 БАЙТ) НЕ ВХОДИТ.
С - БАЙТ ФЛАГОВ. В "ORDOS" V2.X ИСПОЛЬЗУЕТСЯ ТОЛЬКО БИТ D7. СОСТОЯНИЕ "1" УКАЗЫВАЕТ НА ТО,
ЧТО ФАЙЛ ЗАЩИЩЕН ОТ УНИЧТОЖЕНИЯ. ОСТАЛЬНЫЕ БИТЫ ЗАРЕЗЕРВИРОВАНЫ ДЛЯ РАСШИРЕНИЯ. ИЗМЕНЕНИЕ
СОСТОЯНИЯ БИТА D7 ПРОИЗВОДЯТ ВНЕШНИЕ ЗАГРУЖАЕМЫЕ ДИРЕКТИВЫ ОПЕРАЦИОННОЙ СИСТЕМЫ. D-F - СЛУЖЕБНЫЕ ЯЧЕЙКИ СИСТЕМЫ.
}

{
CAS File Format for SYSTEM programs -----------------------------------
binary file contains blocks of data

1st block: header: 256 times '00' and 'A5' synchron byte 2nd block: name: 55, and 6 character name from ASC 'A'-'Z' data block: 3C NN LL HH DD DD DD ... DD CC
where:
3C: signature byte
NN: length of the data block (0 means 256 bytes) HHLL: address of memory
DD DD .. DD: data bytes
CC: checksum
last block: 78 LL HH
where HHLL is the start address of the program }

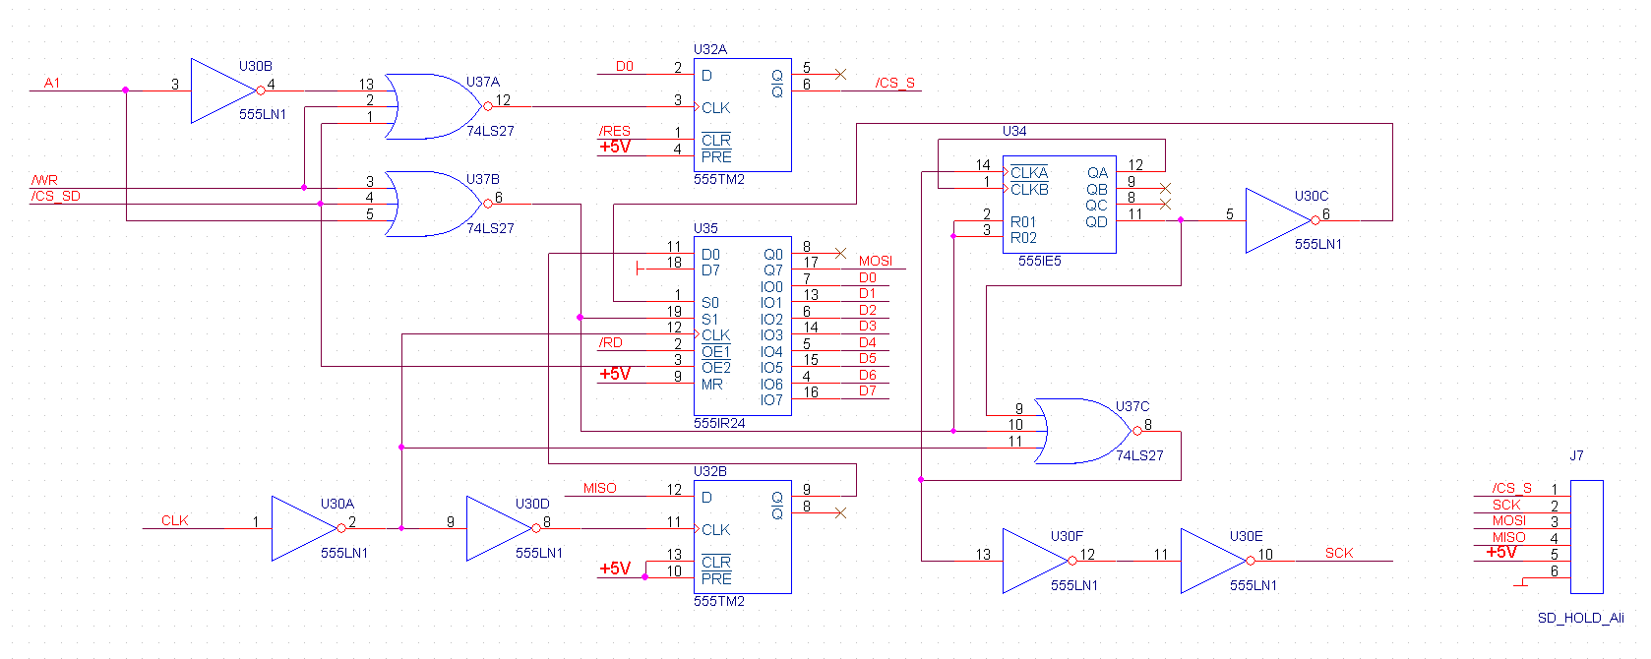
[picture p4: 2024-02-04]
SDOS_V8C_GP40/SCH_SD_HWM_PVV_new_alt1.png

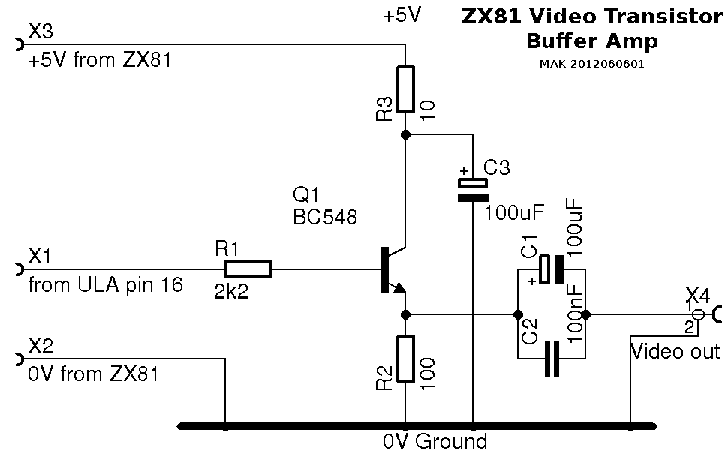
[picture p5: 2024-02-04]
LTspice_composite_video/ZX81_video_buffer.png

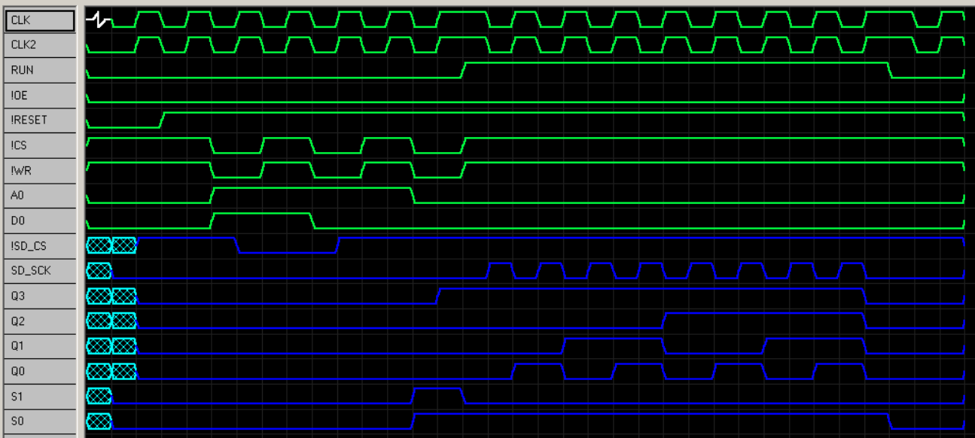
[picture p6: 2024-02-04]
Firmware/U40_PLD/waveform.png

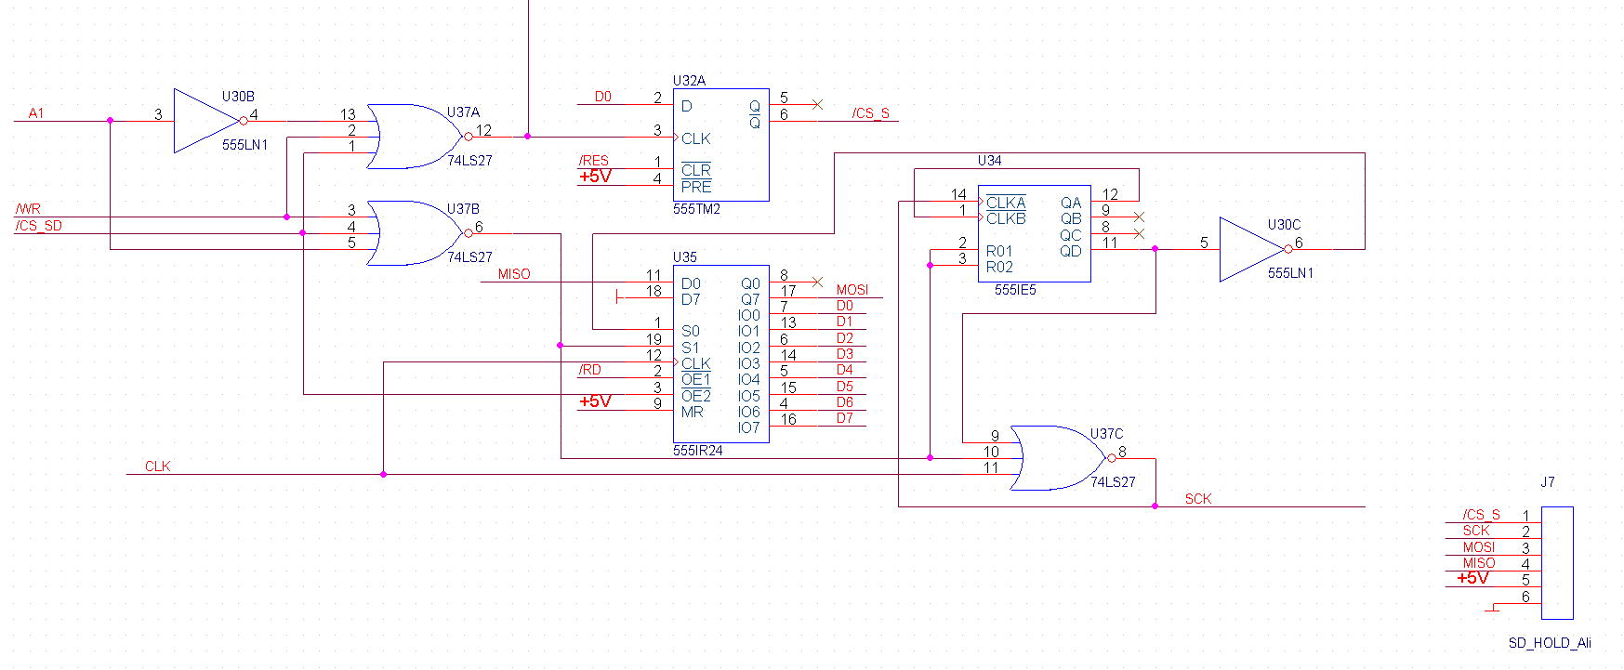
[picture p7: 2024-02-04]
SDOS_V8C_GP40/SCH_SD_HWM_PVV_new_alt2.png

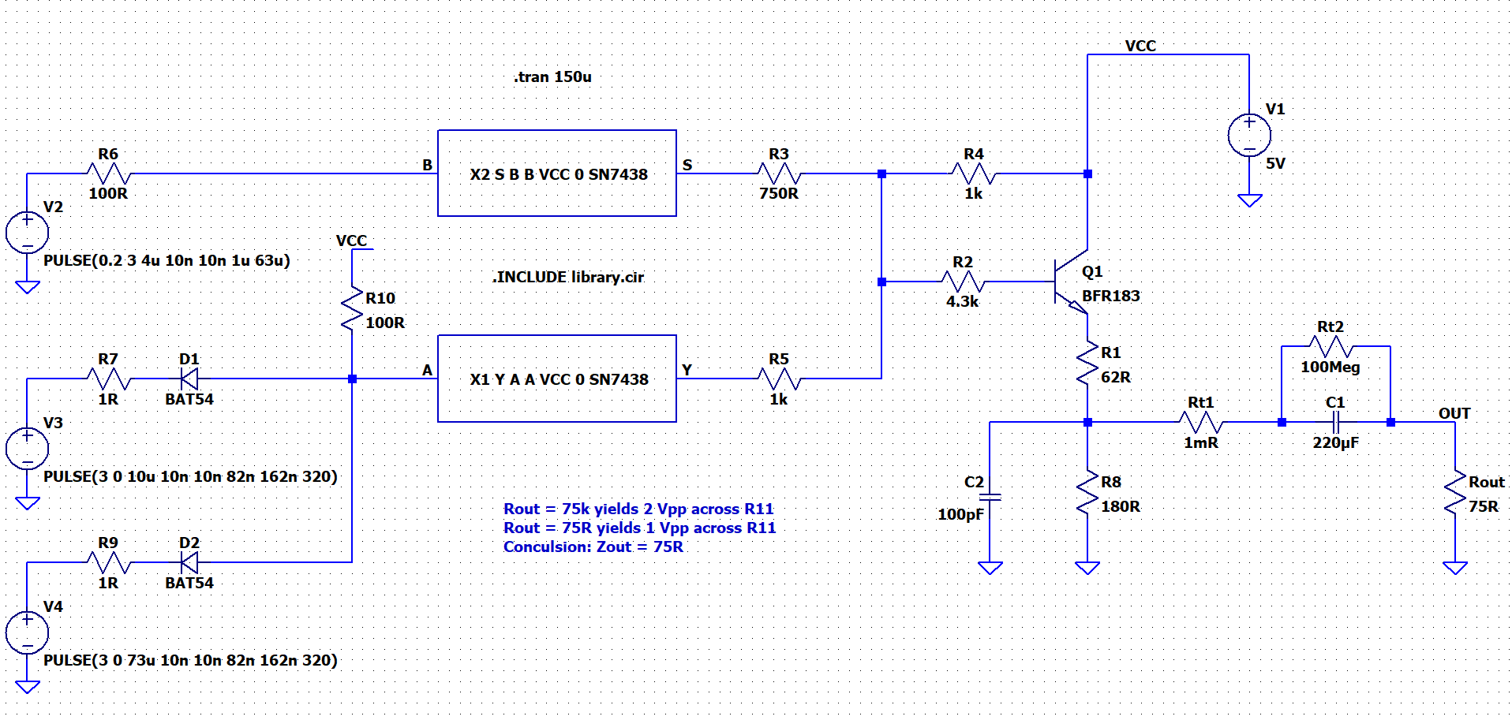
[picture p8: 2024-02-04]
LTspice_composite_video/composite_video.png

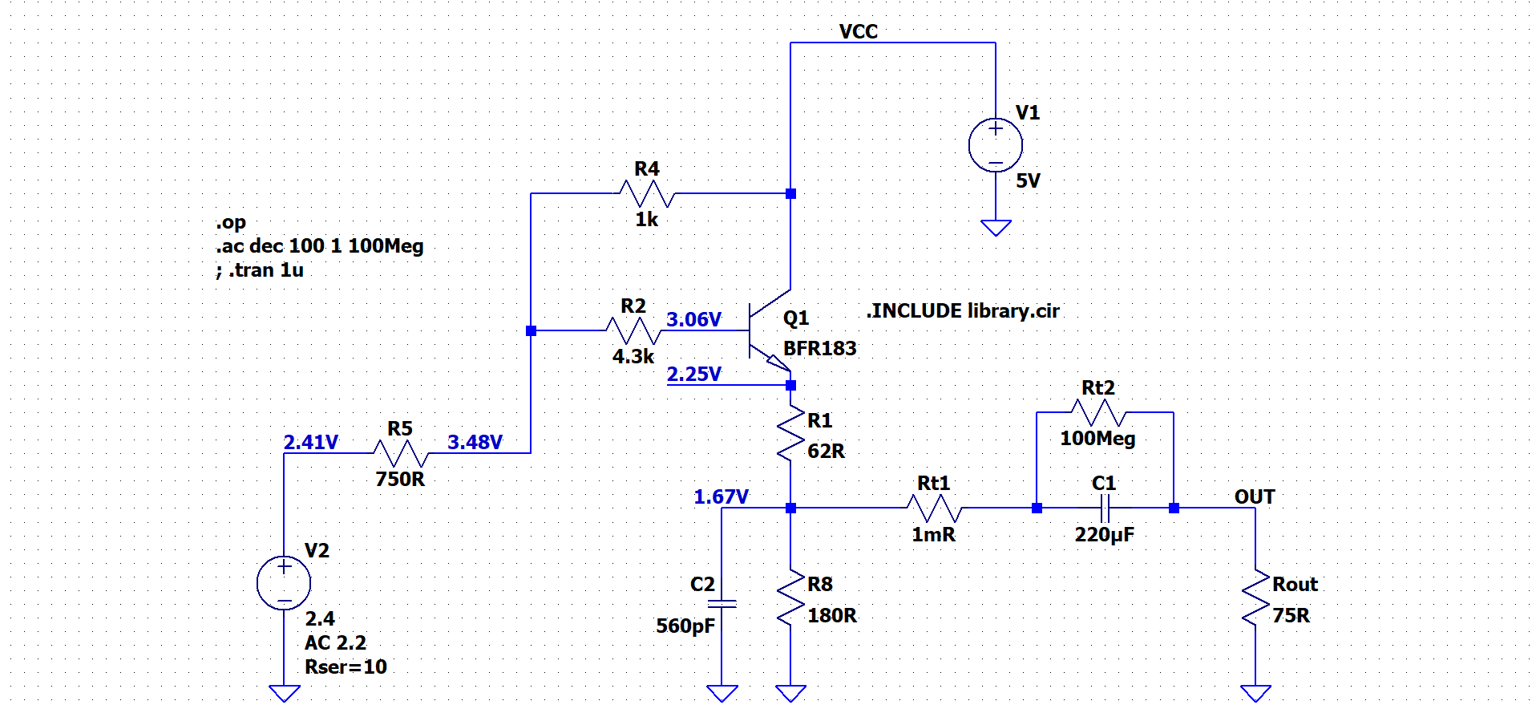
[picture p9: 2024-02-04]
LTspice_composite_video/composite_video_LPF.png

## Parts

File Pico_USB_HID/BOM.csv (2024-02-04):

ID | Name | Designator | Footprint | Quantity | Manufacturer Part | Manufacturer | Supplier | Supplier Part | Price
1 | 0.1u | C1,C2,C3 | C0805_MK | 3
2 | BSS138 | Q1 | SOT-23-3_MK | 1 | BSS138K | Onsemi | Digi-Key | BSS138KCT-ND
3 | 10k | R1 | R0805_MK | 1
4 | 2k-10k | R2,R3,R4,R5,R6,R7,R8,R9,R10 | R0805_MK | 9
5 | RASPBERRY PI PICO | U1 | RASPBERRY PI PICO SMD | 1 | RPi Pico | Raspberry Pi Foundation | Raspberry Pi Foundation | RPi Pico
6 | 2k-10k | RN1 | RES-ARRAY-TH_9P-P2.54-D1.0_MK | 1 | A09-101JP | FH | LCSC | C29541
7 | HDR_1x1 | J4 | HDR-M-2.54_1X1 | 1 |  |  | LCSC | C81276 | 0.007
8 | ULN2803A | U2 | DIP-18-150-SOCKET | 1 | ULN2803A | ST(意法半导体) | LCSC | C73936 | 1.831
9 | HDR_1x3 | J3,J1,J2 | HDR-M-2.54_1X3 | 3 |  |  | LCSC | C180248 | 0.191
10 | Keyboard | P6 | GP40_KBD | 1

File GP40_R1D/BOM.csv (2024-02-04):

ID | Name | Designator | Footprint | Quantity | Manufacturer Part | Manufacturer | Supplier | Supplier Part | Price
1 | FB2K | L1 | R0805_MK | 1
2 | BAT54 | D54,D53,D51,D52,D2,D1 | SOD-123_L2.7-W1.6-LS3.6-RD | 6 | BAT54GWJ | Nexperia | Digi-Key | 1727-7328-1-ND
3 | LVC1G3208 | U3 | SOT-23-6_MK | 1 | SN74LVC1G3208DBVR | TI | Digi-Key | 296-18771-1-ND
4 | 33R | R19,R18 | R0805_MK | 2
5 | 1k | R20,R56,R57,R1,R2,R3,R10,R41,R49 | R0805_MK | 9
6 | BF183 | Q3 | SOT-23-3_MK | 1 | BC847C | Good-Ark | Digi-Key | 4786-BC847CCT-ND
7 | 750R | R9 | R0805_MK | 1
8 | 4k3 | R15 | R0805_MK | 1
9 | 62R | R16 | R0805_MK | 1
10 | 180R | R17 | R0805_MK | 1
11 | 10u | C48,C51,C52,C55 | C1210 | 4
12 | BC847C | Q1,Q2 | SOT-23-3_MK | 2 | BC847C | Good-Ark | Digi-Key | 4786-BC847CCT-ND
13 | 0.1u | C2,C13,C14,C15,C16,C17,C18,C21,C22,C23,C24,C25,C26,C27,C28,C29,C30,C31,C33,C34,C41,C42,C53,C54,C56,CV | C0805_MK | 26
14 | 4n7 | C1 | C0805_MK | 1
15 | 47p | C5 | C0805_MK | 1
16 | 10k | R51,R6,R7,R8,R40 | R0805_MK | 5
17 | 1k5 | R52,R55 | R0805_MK | 2
18 | 3k | R53,R54 | R0805_MK | 2
19 | 1u | C9,C10,C11,C12 | C1210 | 4
20 | 4k7 | R38 | R0805_MK | 1
21 | 18k | R4,R5 | R0805_MK | 2
22 | 2k4 | R11 | R0805_MK | 1
23 | 100R | R14 | R0805_MK | 1
24 | 10nF | C7 | C0805_MK | 1
25 | 0.47u | C20 | C1206 | 1
26 | 22u | C6 | CASE-B_3528 | 1
27 | LVC2G34 | U43,U44 | SOT-23-6_MK | 2 | SN74LVC2G34DBVR | TI | Digi-Key | 296-13496-1-ND
28 | Keyboard | P6 | GP40_KBD | 1
29 | 22n | CH | C0805_MK | 1
30 | 390R | RH | R0805_MK | 1
31 | 27k | RV | R0805_MK | 1
32 | 10u | C49 | C0805_MK | 1
33 | 0.1u | C46,C44,C43,C45 | C0603_MK | 4
34 | 33R | R26 | R0603_MK | 1
35 | ATF16V8B | U40,U2 | DIP-20-150-SOCKET | 2 | ATF16V8B-15PU | Atmel | Digi-Key | ATF16V8B-15PU
36 | HCT299 | U41 | DIP-20-150-SOCKET | 1
37 | TLV1117-33 | U42 | SOT-223-4_L6.5-W3.5-P2.30-LS7.0-BR | 1 | TLV1117-33CDCY | TI | RS-Online | 660-7975
38 | CT1102V | P2,P8 | KEY-TH_CT1102V3.15 | 2 | CT1102V5.85F260 | CIT Relay and Switch | Digi-Key | 2449-CT1102V5.85F260-ND
39 | 4n7 n.p. | CS2 | RAD-0.1 | 1
40 | Super bright | LED | LED-TH_BD3.0_RED | 1 | 204-10SDRD/S530-A3-L | EVERLIGHT(台湾亿光) | LCSC | C84774 | 0.029
41 | 470u | C19 | CASE-D_7343 | 1
42 | HCT04 | U1 | DIP-14-150-SOCKET | 1
43 | HCT00 | U4 | DIP-14-150-SOCKET | 1
44 | 27C64 | U5 | DIP-28-600-SOCKET | 1 | AT27C512R-45PU | Microchip | Digi-Key | AT27C512R-45PU-ND
45 | HCT74 | U6 | DIP-14-150-SOCKET | 1
46 | LS38 | U9 | DIP-14-150-SOCKET | 1
47 | HCT574 | U10 | DIP-20-150-SOCKET | 1
48 | 27C128 | U11 | DIP-28-600-SOCKET | 1 | AT27C512R-45PU | Microchip | Digi-Key | AT27C512R-45PU-ND
49 | HCT166 | U12 | DIP-16-150-SOCKET | 1
50 | HCT93 | U13 | DIP-14-150-SOCKET | 1
51 | LS145 | U14 | DIP-16-150-SOCKET | 1
52 | HCT4040 | U16 | DIP-16-150-SOCKET | 1
53 | HC4017 | U17 | DIP-16-150-SOCKET | 1
54 | HCT123 | U18 | DIP-16-150-SOCKET | 1
55 | HCT251 | U19 | DIP-16-150-SOCKET | 1
56 | HCT02 | U52 | DIP-14-150-SOCKET | 1
57 | MEM2075-00-140-01-A | CARD1 | MEM2075-00-140-01-A_MK | 1 | MEM2075-00-140-01-A | GCT | Digi-Key | 2073-MEM2075-00-140-01-ACT-ND
58 | HDR_1x20 | P7 | HDR-M-2.54_1X20_MK | 1 |  |  | LCSC | C50981 | 0.092
59 | Z80A | U8 | DIP-40-SOCKET | 1 | Z84C0008PEG | ZiLOG, Inc. | RS-Online | 625-8918
60 | YM2149F | U51 | DIP-40-SOCKET | 1
61 | 62256 | U7 | DIP-28-600-SOCKET | 1 | AS6C62256-55PCN | Alliance | RS-Online | 538-148
62 | 6.144MHz | X1 | OSC-TH_L10.0-W4.5-P5.00 | 1 | QCL6.14400F18B23B | Quantek | RS-Online | 814-9409
63 | 10k | R27 | R0603_MK | 1
64 | HDR_1x2 | P3B,P5,P4 | HDR-M-2.54_1X2 | 3 |  |  | LCSC | C124375 | 0.023
65 | 3k3 | R22,R23,R24,R25 | R0603_MK | 4
66 | PJ-102AH | P1 | DC-IN-TH_PJ-102AH | 1 | PJ-102AH | null | Electrokit | 41013585
67 | HDRF_1x6 | P21 | HDR-TH_6P-P2.54-V-F | 1 | 2.54-1*6P母 | BOOMELE(博穆精密) | LCSC | C40877 | 0.073
68 | PJ-324 3.5mm | P51 | AUDIO-TH_PJ324 | 1 | PJ-324 3.5mmAudio sockets | ReliaPro | Electrokit | 41001189
69 | HDR_1x18 | P9,P10 | HDR-TH_18P-P2.54-V-M | 2 | KH-2.54PH180-1X18P-L11.5 | kinghelm(金航标) | LCSC | C2905492 | 0.139
70 | 100uF | C32,C8,C39,C40 | CASE-D_7343 | 4
71 | RCA_CBP | P3 | RCA_CBP | 1 |  |  | Electrokit | 41001410
72 | 10k | RN1,RN2 | RES-ARRAY-TH_9P-P2.54-D1.0_MK | 2 | A09-101JP | FH | LCSC | C29541
73 | 39pF | CS1 | RAD-0.1 | 1

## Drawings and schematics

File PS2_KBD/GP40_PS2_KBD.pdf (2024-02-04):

# A7 3 A6 4 A5 5 A4 6 A3 7 A2 8 A1 9 A0 10

# D7 19 D6 18 D5 17 D4 16 D3 15 D2 13 D1 12 D0 11

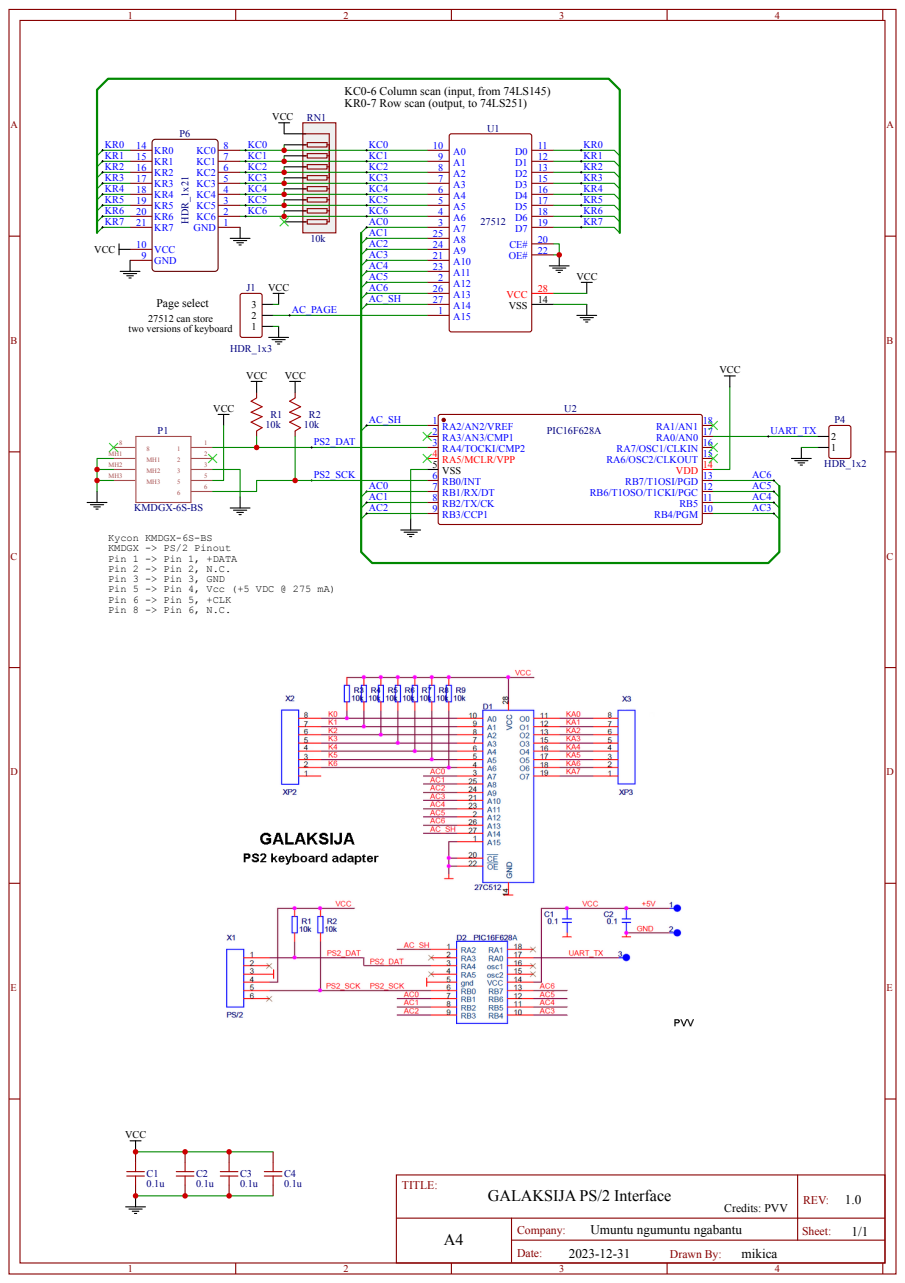
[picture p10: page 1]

KC0-6 Column scan (input, from 74LS145)
KR0-7 Row scan (output, to 74LS251)

Page select
27512 can store
two versions of keyboard

Kycon KMDGX-6S-BS
KMDGX -> PS/2 Pinout
Pin 1 -> Pin 1, +DATA
Pin 2 -> Pin 2, N.C.
Pin 3 -> Pin 3, GND
Pin 5 -> Pin 4, Vcc (+5 VDC @ 275 mA)
Pin 6 -> Pin 5, +CLK
Pin 8 -> Pin 6, N.C.

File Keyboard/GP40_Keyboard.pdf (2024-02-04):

A

H

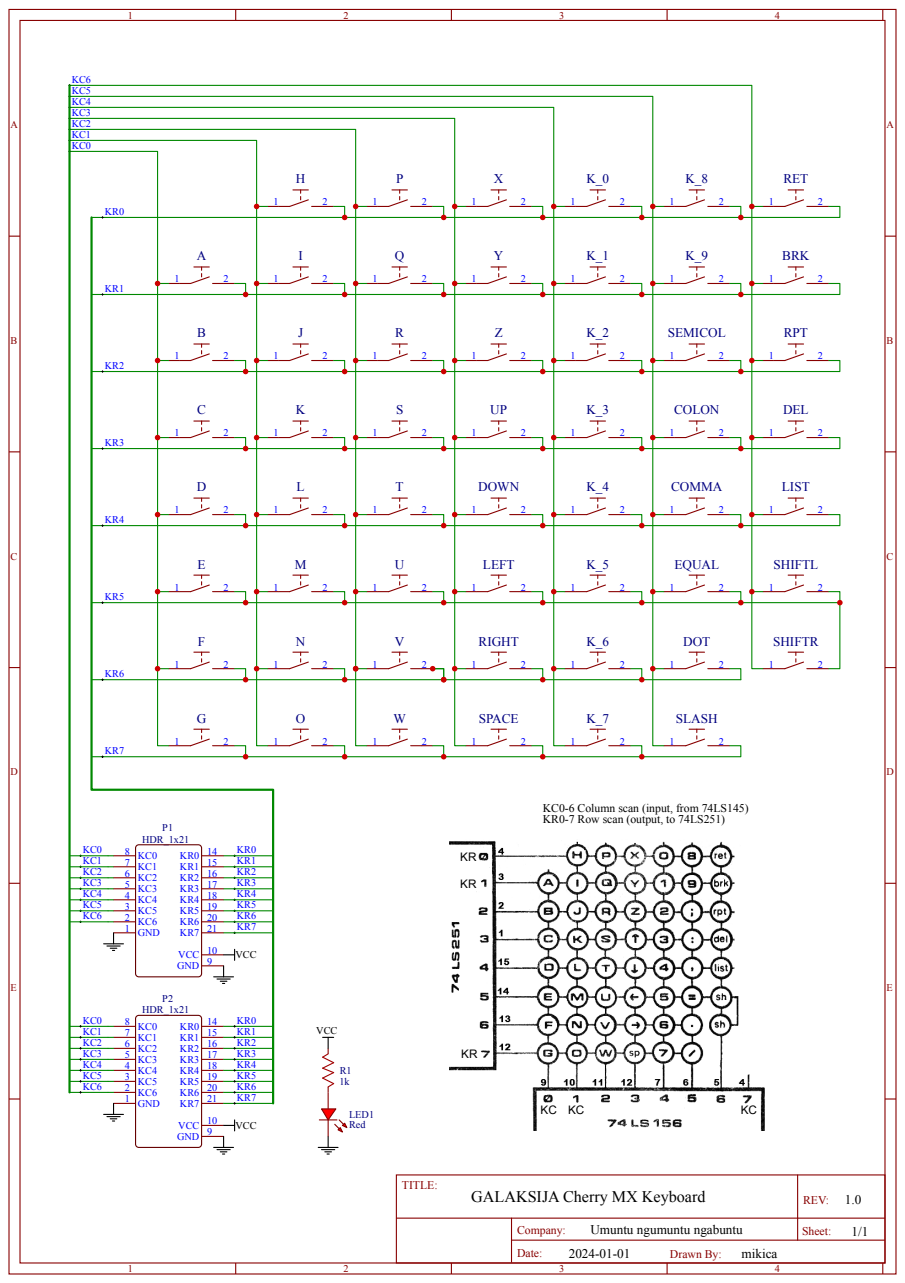
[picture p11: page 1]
TITLE:; GALAKSIJA Cherry MX Keyboard; REV:; Date:; Sheet:; Drawn By:; mikica; Company:; Umuntu ngumuntu ngabuntu; DOWN; LEFT; RIGHT; SPACE; SEMICOL; COLON; COMMA; EQUAL; DOT; SLASH; SHIFTR; SHIFTL; LIST; DEL; RPT; BRK; RET; HDR_1x21; GND 1 KC6 2 KC5 3 KC4 4 KC3 5 KC2 6 KC1 7 KC0 8; VCC 10 GND 9; VCC; Red; LED1

KC0-6 Column scan (input, from 74LS145)
KR0-7 Row scan (output, to 74LS251)

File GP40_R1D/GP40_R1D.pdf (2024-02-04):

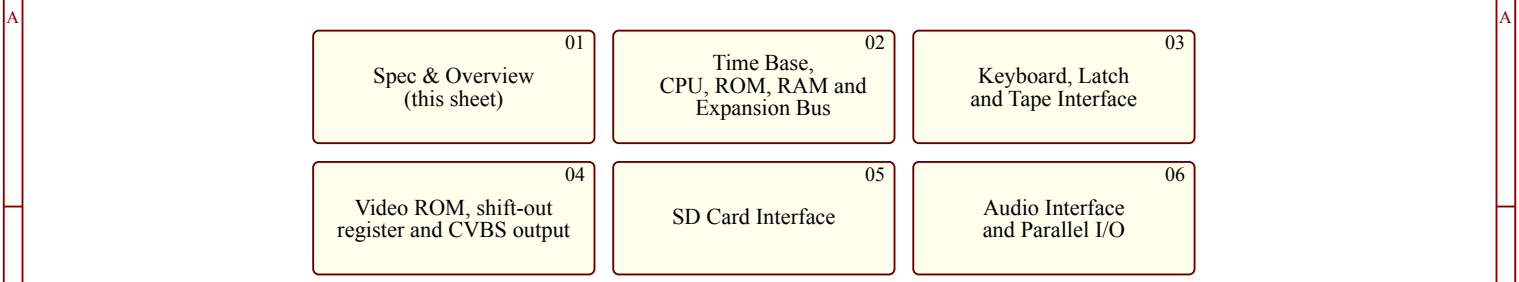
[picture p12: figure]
Time Base, CPU, ROM, RAM and Expansion Bus; SD Card Interface; Audio Interface; and Parallel I/O; Keyboard, Latch and Tape Interface; Video ROM, shift-out register and CVBS output; Spec & Overview (this sheet)

B | B
C | C
D | D
E | E
TITLE: | GALAKSIJA 40th Anniversary Tribute | REV: | R1D
Date: | 2024-02-04
Sheet: | 1/6
Drawn By: | mikica
Company: | Umuntu ngumuntu ngabantu

### SPECIFICATIONS

- Z80A CPU at 3.072 MHz, 32 kB ROM (16k used), 32 kB static RAM - Text mode 32x16 characters, monochrome - Graphics mode: 256x208 pixels - Storage: cassette tape (280 or 1200 bit/s) MicroSD card (up to 4 GB) with SDOS - Sound: 3 channels + white noise provided by AY-3-8910 or YM2149F - I/O ports: two 8-bit parallel ports - USB HID keyboard/mouse interface (as add-on) - Power consumption: less than 250mA at 5V

### This Galaksija Plus mod is based on PVV's clone from 2017 with the following modifications:

### - stable composite video (no need to reduce the power in voltage)

- address decoder with ATF16V8B (or some older GAL16V8 equivalent),

which provides a configurable memory map with 1 kB granularity - improved PVV SD hardware (SD now runs on the CPU clock) - integrated micro SD socket with LVTTL level shifters - integrated audio interface - two I/O ports connected to the audio interface - NMI reset circuit - hybrid TH/SMD PCB (SMD discrete components on the bottom side) - board dimensions 100x190 mm - a keyboard stackable either on the upper or the bottom side

### Distributed with the following ROM images:

### - GP40_V8C.BIN with SDOS v8.12 (fits an EPROM 16k-64k) - GP40_CHRGEN.BIN (fits an EPROM 8k-64k)

### Hardware memory map:

$0000...$0FFF ROM A or 1: 4 kB (bootstrap and BASIC) $1000...$1FFF ROM B or 2: 4 kB (math functions, etc.) $2000...$27FF Keyboard and latch $2800...$BFFF RAM: 30 kB ($2800...$2BFF Video RAM) $C000...$C7FF RAM: 2 kB (used by SDOS) $C800...$CFFF PVV HW SD interface: 2 kB $D000...$DFFF Unused, 4 kB (routed to CS on the expansion bus) $E000...$EFFF ROM 3: 4 KB (Galaksija Plus, graphics) $F000...$FFFF ROM 3: 4 KB (SDOS)

### Credits:

- Voja Antonic: Galaksija (1983) - Nenad Dunjic and Milan Tadic: Galaksija Plus mod (1985) - PVV and Fifan: Galaksija Plus clone with SD card (2016) http://www.nedopc.org/forum/viewtopic.php?p=87313 - Goran Stankovic (YT2FSG): Retro Computers web page https://www.qsl.net/yt2fsg/galaksija/galaksija_clone.html - Retro Bertie (@MacBerti28): YouTube guide

### Soldering sequence:

### 1. start with the SMD components on the bottom side (the SMD components are 0805+ and easy to solder) 2. solder the SMD components on the top side 3. solder the IC sockets 4. solder the rest of the components

A4

R1C -> R1D:
1) connected \RESET to kbd P6 pin 12 (for ctrl-alt-del)
2) disconnected kbd P6 pin 13 from ground
3) connected A10 to U2 pin 6 (yields 1k granularity)
4) \NMS & \RESET for audio (logical or using diodes)
5) accommodated USB HID add-on

R1A -> R1C:
1) redesigned SD interface to use 2 ICs
2) added RESET and NMI buttons
3) added two 8-bit I/O ports
4) kbd P6 pins 11-13 connected to GND

Changelog
Note:
- NMI switch is very close to U6 so U6 must be in a socket.

# Q12 1 Q11 15 Q10 14 Q9 12 Q8 13 Q7 4 Q6 2 Q5 3 Q4 5 Q3 6 Q2 7 Q1 9

## Time Base

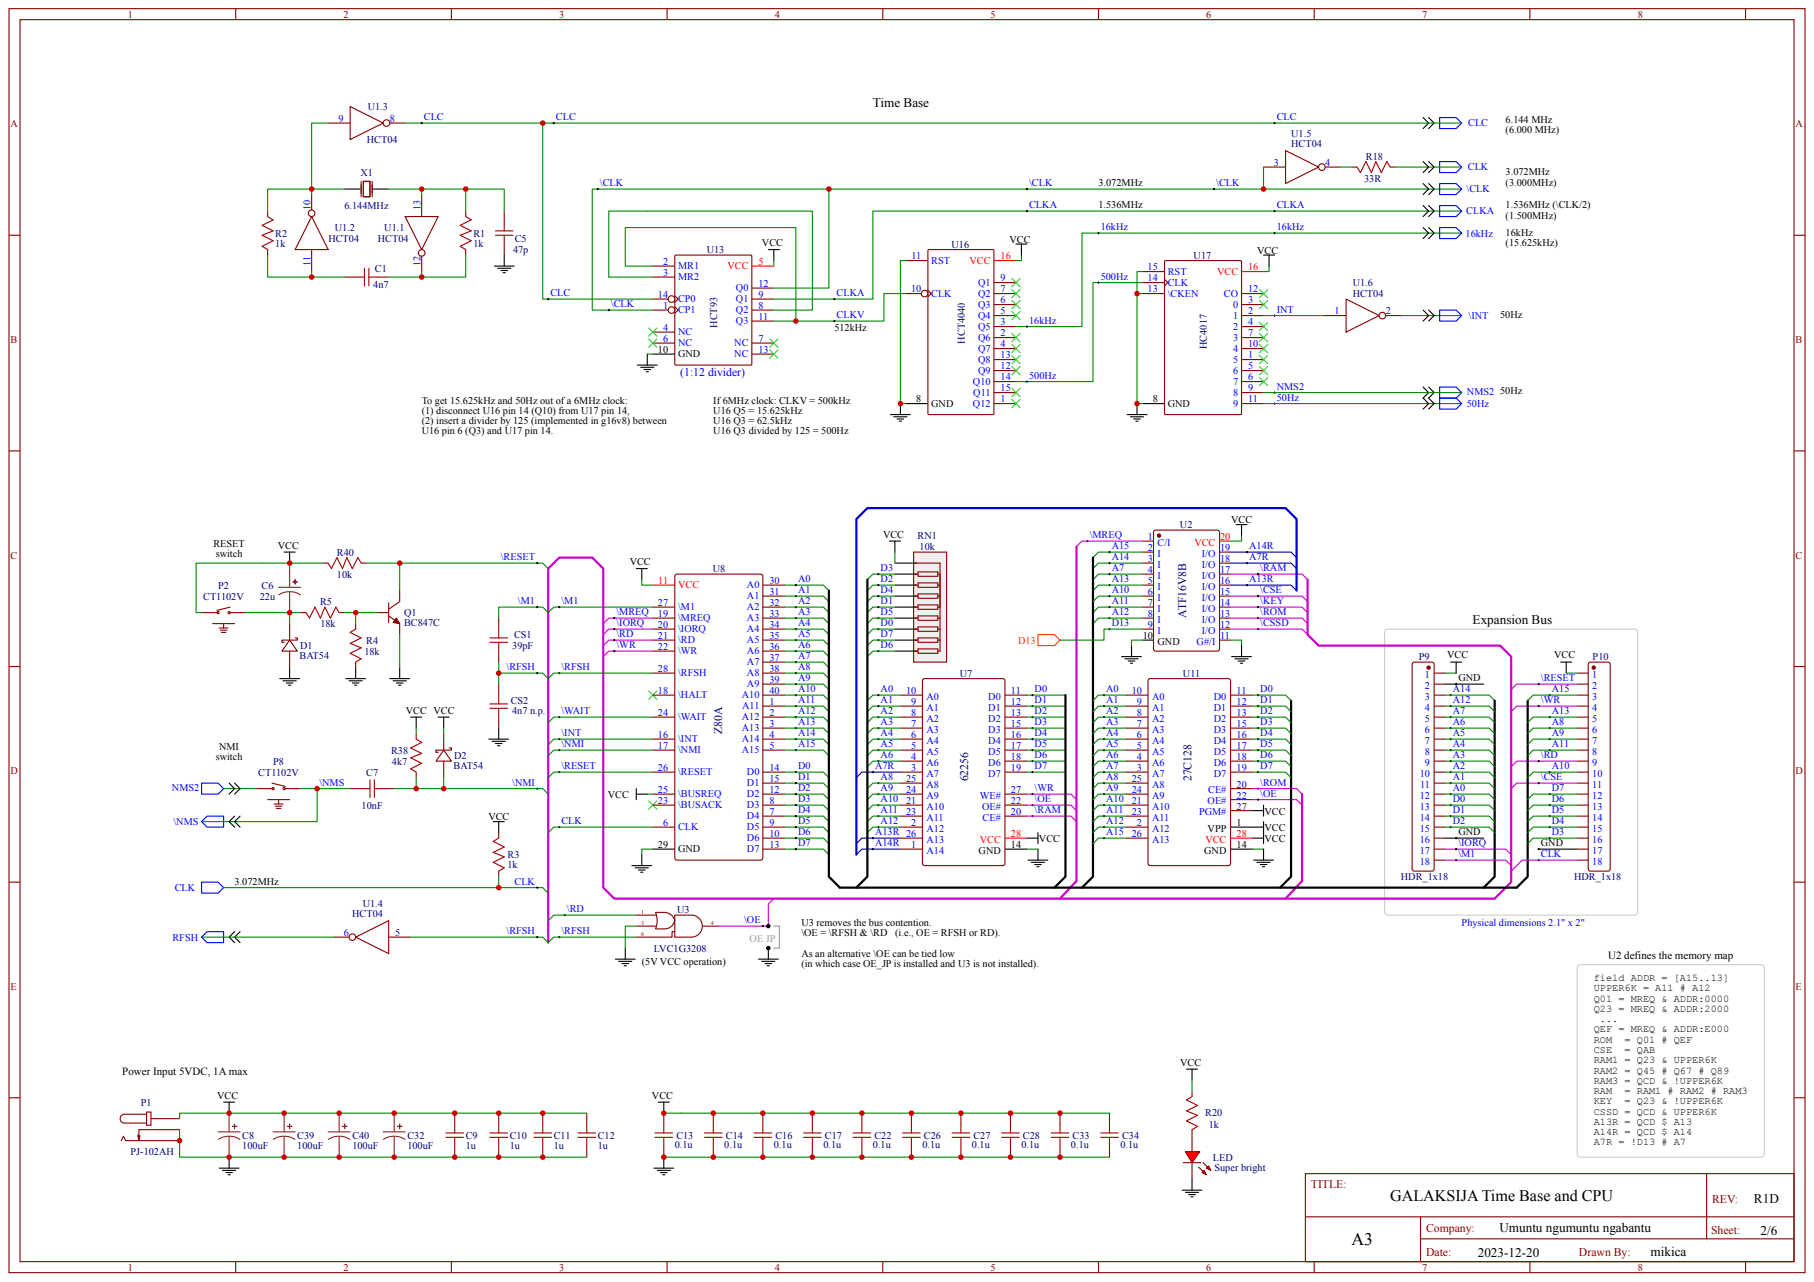
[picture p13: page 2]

To get 15.625kHz and 50Hz out of a 6MHz clock:
(1) disconnect U16 pin 14 (Q10) from U17 pin 14,
(2) insert a divider by 125 (implemented in g16v8) between
U16 pin 6 (Q3) and U17 pin 14.

\WR 22 \RD 21 \IORQ 20 \MREQ 19 \M1 27

U3 removes the bus contention.
\OE = \RFSH & \RD (i.e., OE = RFSH or RD).
As an alternative \OE can be tied low
(in which case OE_JP is installed and U3 is not installed).

U2 defines the memory map
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

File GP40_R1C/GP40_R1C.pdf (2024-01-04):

A | A

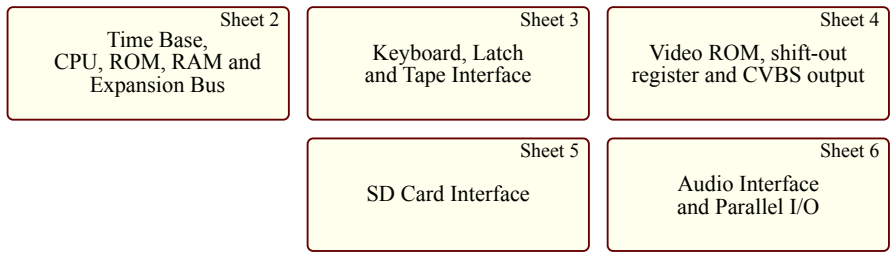
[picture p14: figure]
SD Card Interface; Audio Interface; and Parallel I/O; Keyboard, Latch and Tape Interface; Time Base, CPU, ROM, RAM and Expansion Bus; Video ROM, shift-out register and CVBS output; Sheet 2; Sheet 3; Sheet 5; Sheet 4; Sheet 6

B | B
C | C
D | D
E | E
TITLE: | GALAKSIJA 40th Anniversary Tribute | REV: | 1.03
Date: | 2024-01-04
Sheet: | 1/6
Drawn By: | mikica
Company: | Umuntu ngumuntu ngabantu

### SPECIFICATIONS

- Z80A CPU at 3.072 MHz, 32 kB ROM (16k used), 32 kB static RAM - Storage: cassette tape (280 or 1200 bit/s) or SD card with SDOS - Text mode 32x16 characters, monochrome - Graphics mode: 256x208 pixels - Sound: 3 channels + white noise provided by AY-3-8910 or YM2149F - I/O ports: two 8-bit parallel ports

### This mod is based on PVV's Galaksija Plus clone from 2017 with the following modifications:

- improved PVV SD hardware (SD now runs on CPU clock) - integrated micro SD socket with level shifters - integrated audio interface - two I/O ports connected to the audio interface - address decoder with ATF16V8B (or some older GAL16V8 equivalent) - NMI reset circuit - hybrid TH/SMD PCB (SMD discrete components on the bottom side) - board dimensions 100x190 mm with a keyboard stackable either on the upper or the bottom side

### Distributed with the following ROM images:

### - GALAKSIJA_v8C.BIN with SDOS v8.12 (fits an EPROM 16k-64k) - GALAKSIJA_CHRGEN.BIN (fits an EPROM 8k-64k)

### Hardware memory map:

$0000...$0FFF ROM A or 1: 4 kB (Bootstrap) $1000...$1FFF ROM B or 2: 4 kB (Math functions, monitor etc.) $2000...$27FF Keyboard and latch $2800...$BFFF RAM: 30 kB ($2800...$2BFF Video RAM) $C000...$C7FF RAM: 2 kB (used by SDOS) $C800...$CFFF PVV SD interface $D000...$DFFF Unused (routed to CS on the expansion bus) $E000...$EFFF ROM 3: 4 KB (Galaksija Plus graphics) $F000...$FFFF ROM 3: 4 KB (SDOS)

### Credits:

- Voja Antonic: Galaksija (1983) - Nenad Dunjic and Milan Tadic: Galaksija Plus mod (1985) - PVV and Fifan: Galaksija Plus clone with SD card (2016) http://www.nedopc.org/forum/viewtopic.php?p=87313 - Goran Stankovic (YT2FSG): Retro Computers web page https://www.qsl.net/yt2fsg/galaksija/galaksija_clone.html - Retro Bertie (@MacBerti28): YouTube guide

### Soldering sequence:

### 1. start with the SMD components on the bottom side (the SMD components are 0805+ and easy to solder) 2. solder the SMD components on the top side 3. solder the IC sockets 4. solder the rest of the components

A4

# Q12 1 Q11 15 Q10 14 Q9 12 Q8 13 Q7 4 Q6 2 Q5 3 Q4 5 Q3 6 Q2 7 Q1 9

## Time Base

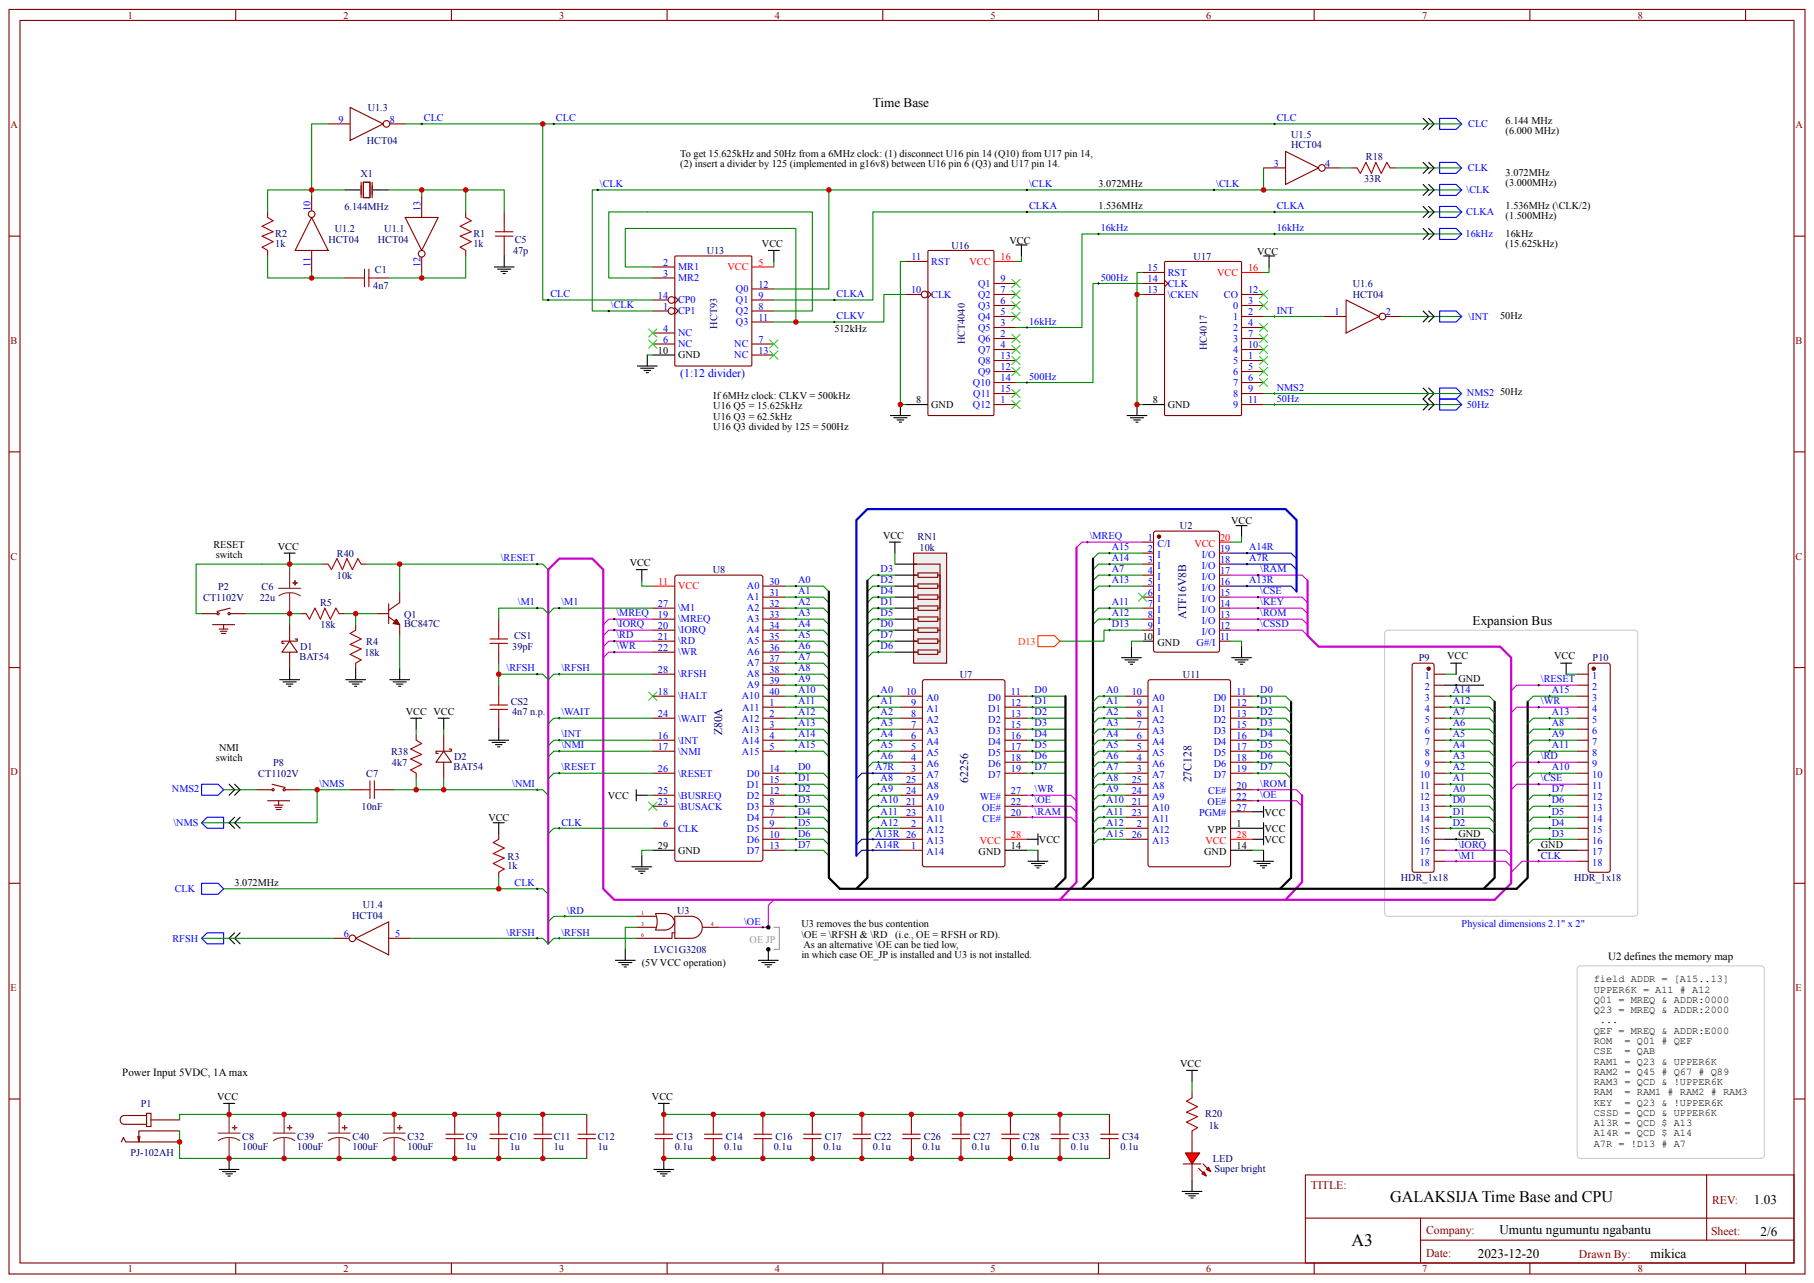
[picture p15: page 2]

To get 15.625kHz and 50Hz from a 6MHz clock: (1) disconnect U16 pin 14 (Q10) from U17 pin 14,
(2) insert a divider by 125 (implemented in g16v8) between U16 pin 6 (Q3) and U17 pin 14.

\WR 22 \RD 21 \IORQ 20 \MREQ 19 \M1 27

U3 removes the bus contention
\OE = \RFSH & \RD (i.e., OE = RFSH or RD).
As an alternative \OE can be tied low,
in which case OE_JP is installed and U3 is not installed.

U2 defines the memory map

## Line-in Tape Interface (optional)

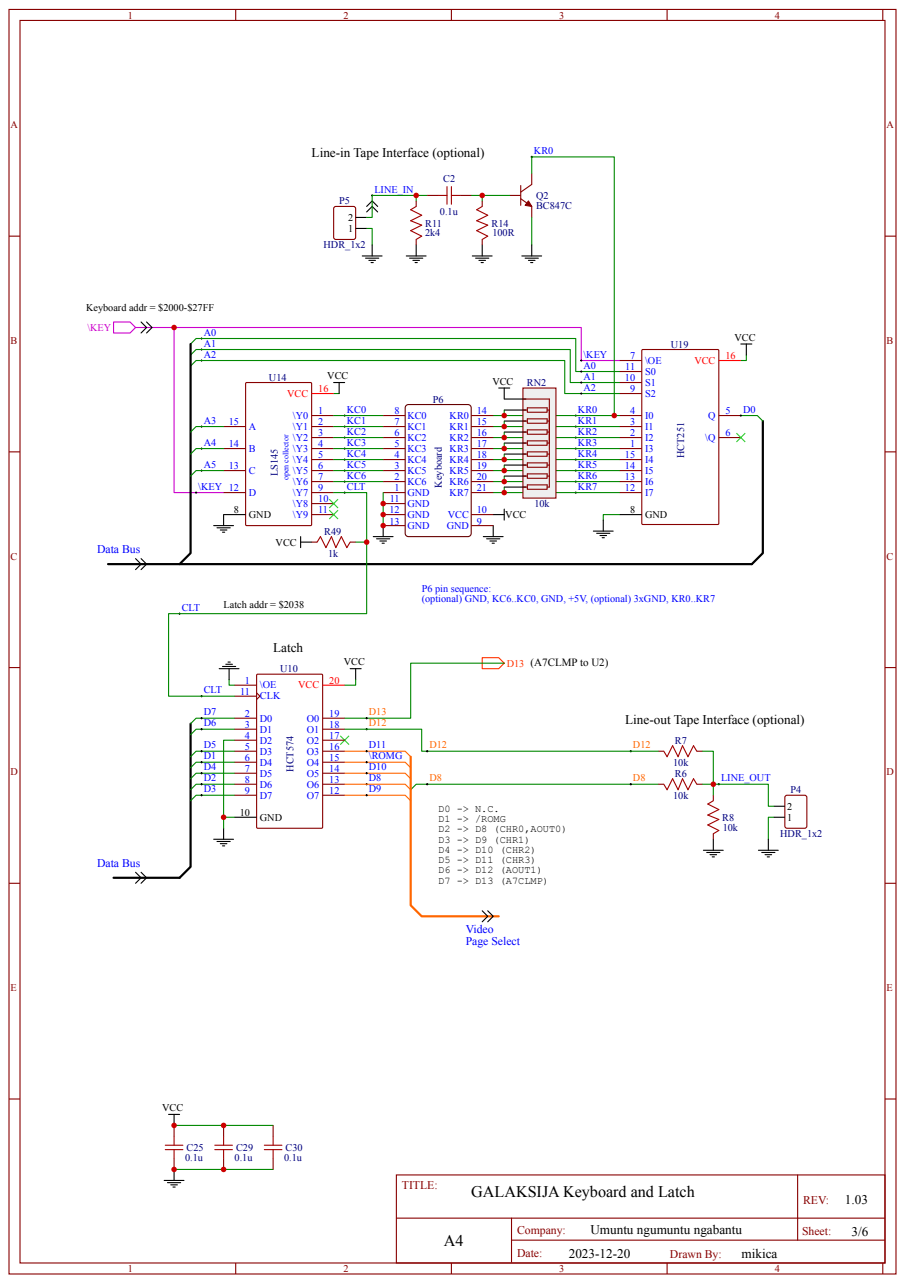
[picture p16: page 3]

P6 pin sequence:
(optional) GND, KC6..KC0, GND, +5V, (optional) 3xGND, KR0..KR7

Line-out Tape Interface (optional)

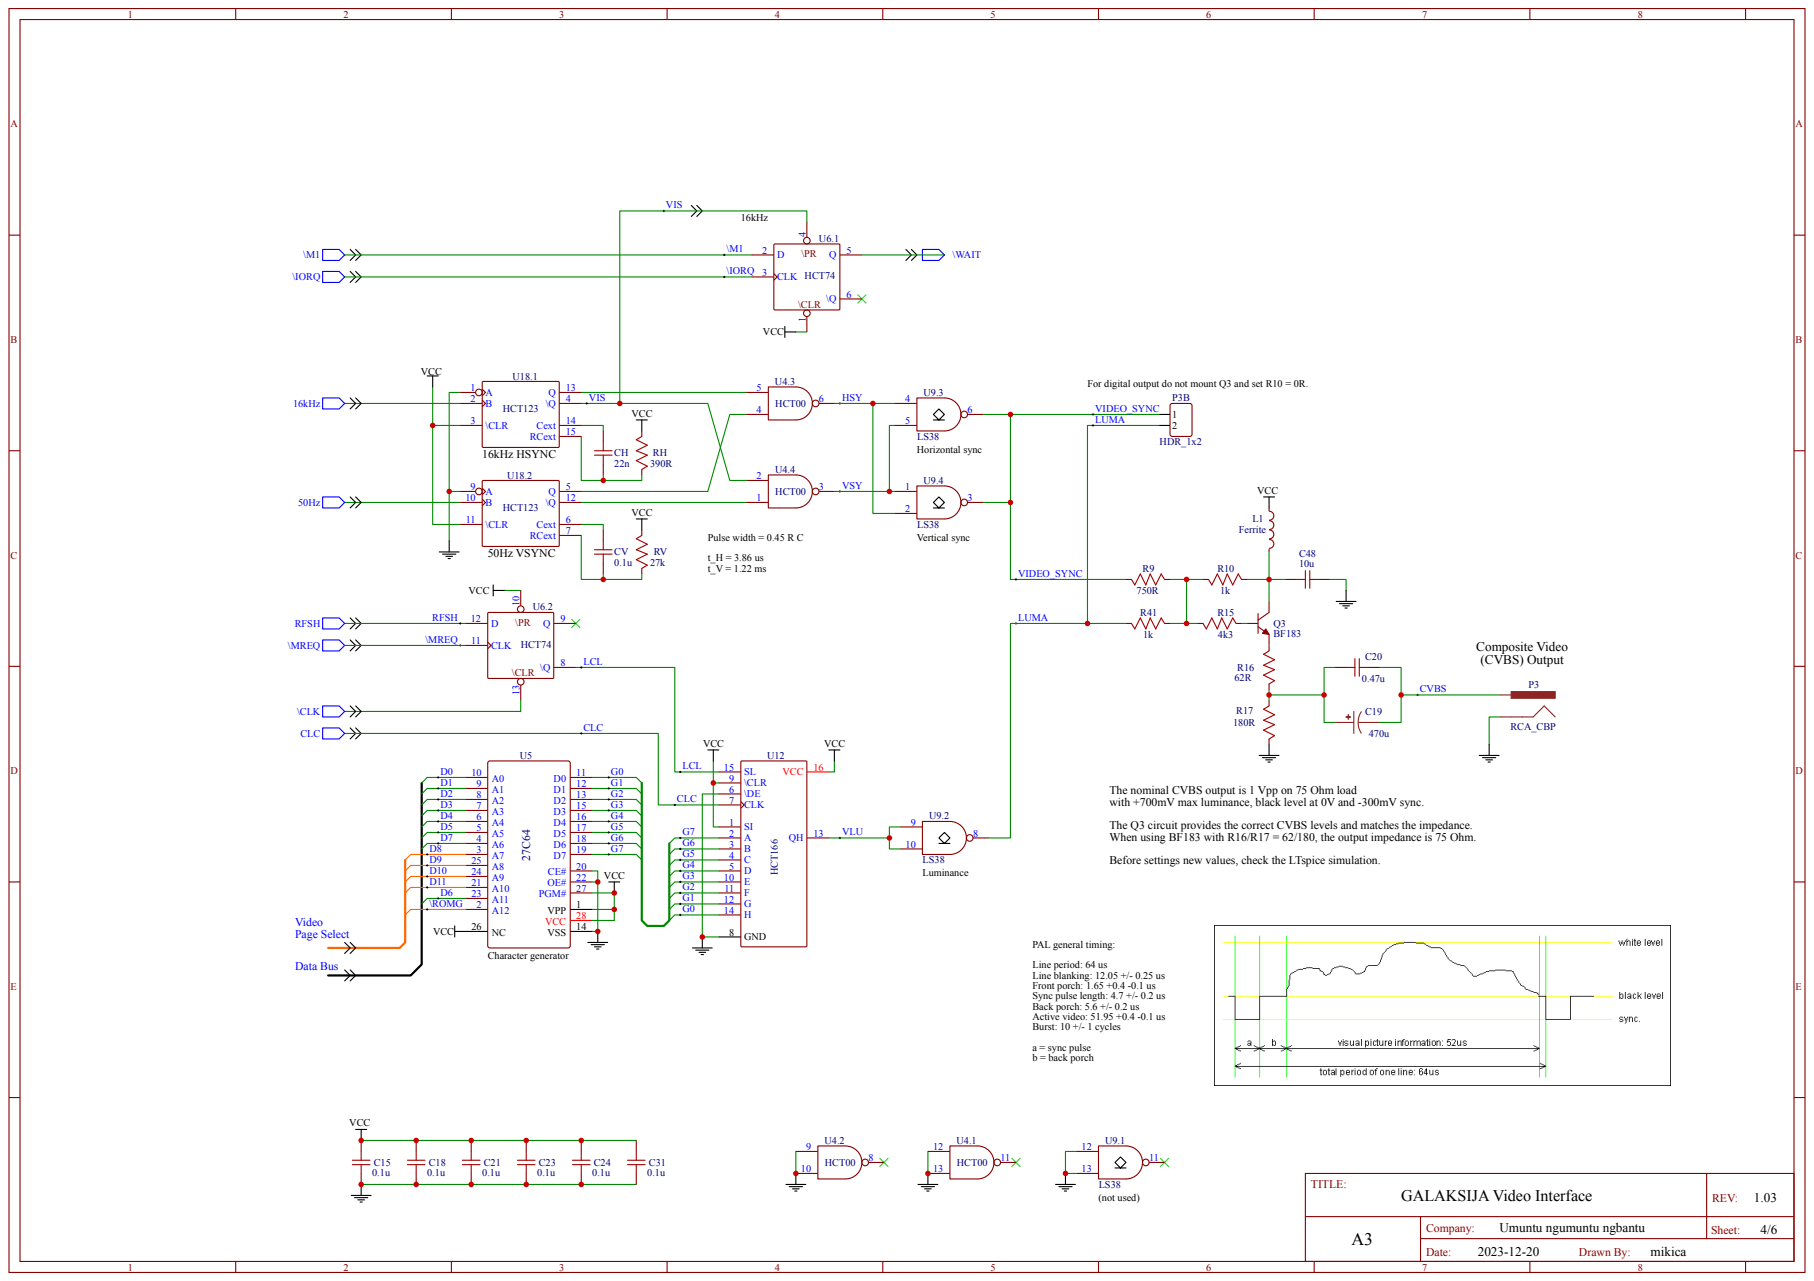
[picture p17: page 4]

For digital output do not mount Q3 and set R10 = 0R.

The nominal CVBS output is 1 Vpp on 75 Ohm load
with +700mV max luminance, black level at 0V and -300mV sync.
The Q3 circuit provides the correct CVBS levels and matches the impedance.
When using BF183 with R16/R17 = 62/180, the output impedance is 75 Ohm.
Before settings new values, check the LTspice simulation.

PAL general timing:
Line period: 64 us
Line blanking: 12.05 +/- 0.25 us
Front porch: 1.65 +0.4 -0.1 us
Sync pulse length: 4.7 +/- 0.2 us
Back porch: 5.6 +/- 0.2 us
Active video: 51.95 +0.4 -0.1 us
Burst: 10 +/- 1 cycles
a = sync pulse
b = back porch

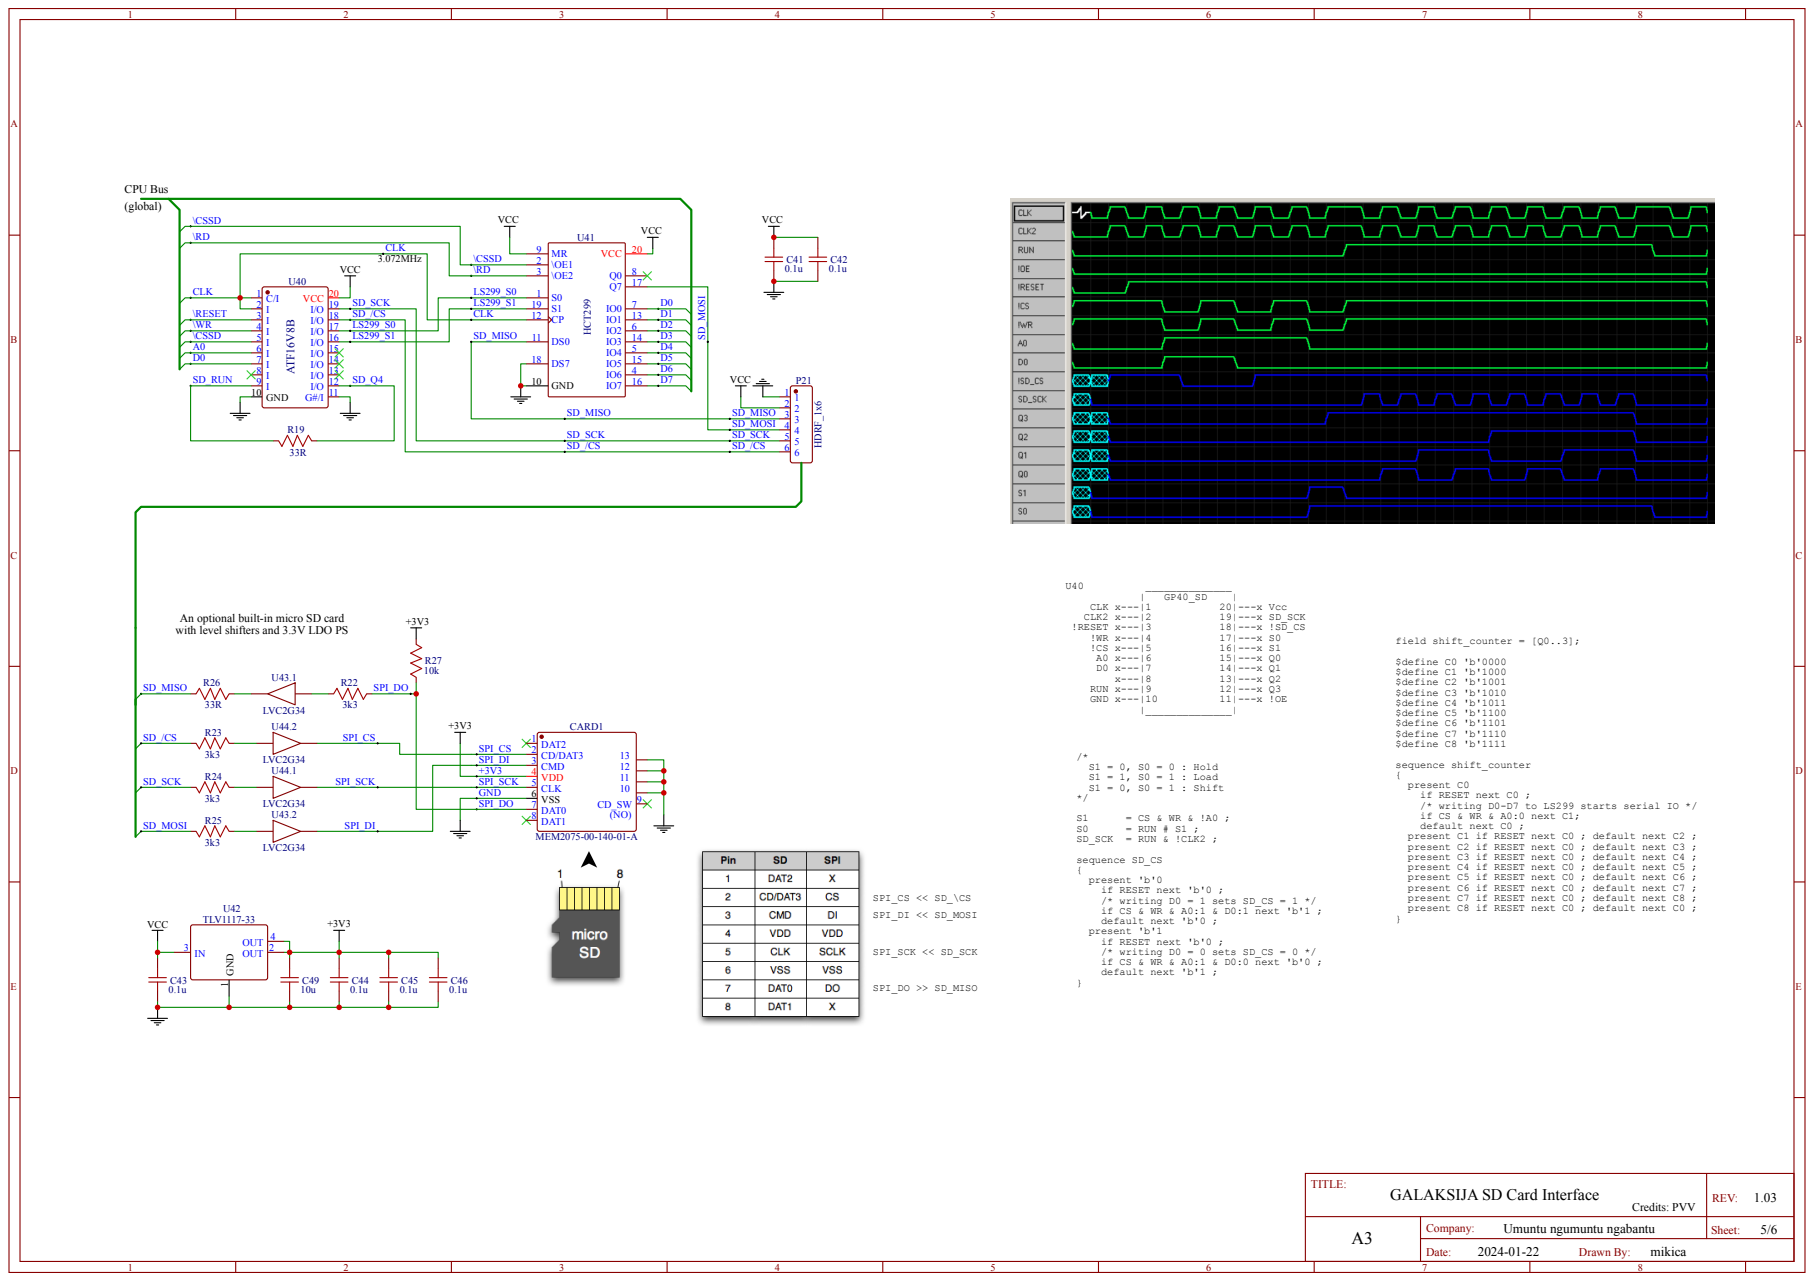
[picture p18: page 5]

An optional built-in micro SD card
with level shifters and 3.3V LDO PS

present C2 if RESET next C0 ; default next C3 ;
present C3 if RESET next C0 ; default next C4 ;
present C4 if RESET next C0 ; default next C5 ;
present C5 if RESET next C0 ; default next C6 ;
present C6 if RESET next C0 ; default next C7 ;
present C7 if RESET next C0 ; default next C8 ;
present C8 if RESET next C0 ; default next C0 ;

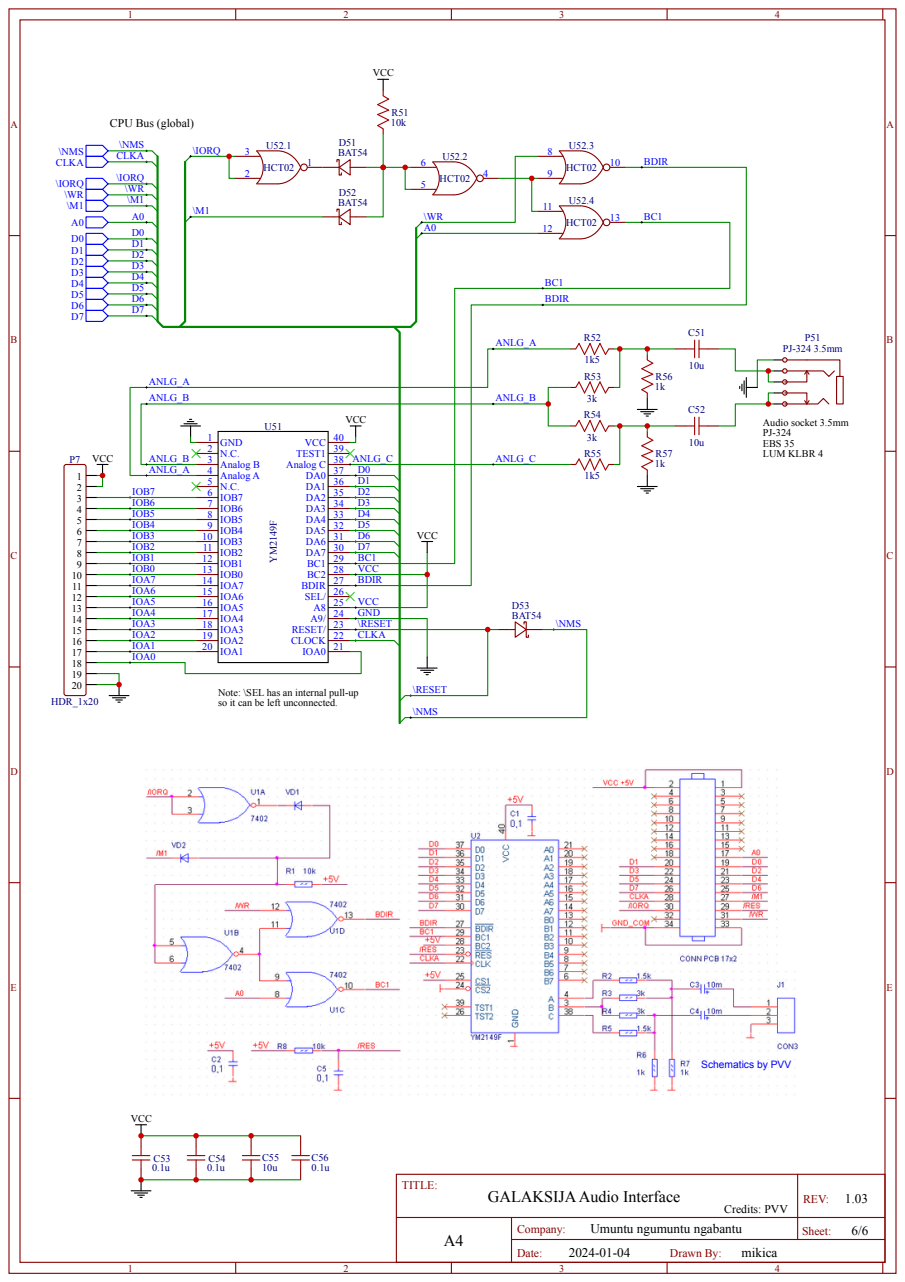
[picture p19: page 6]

Note: \SEL has an internal pull-up
so it can be left unconnected.

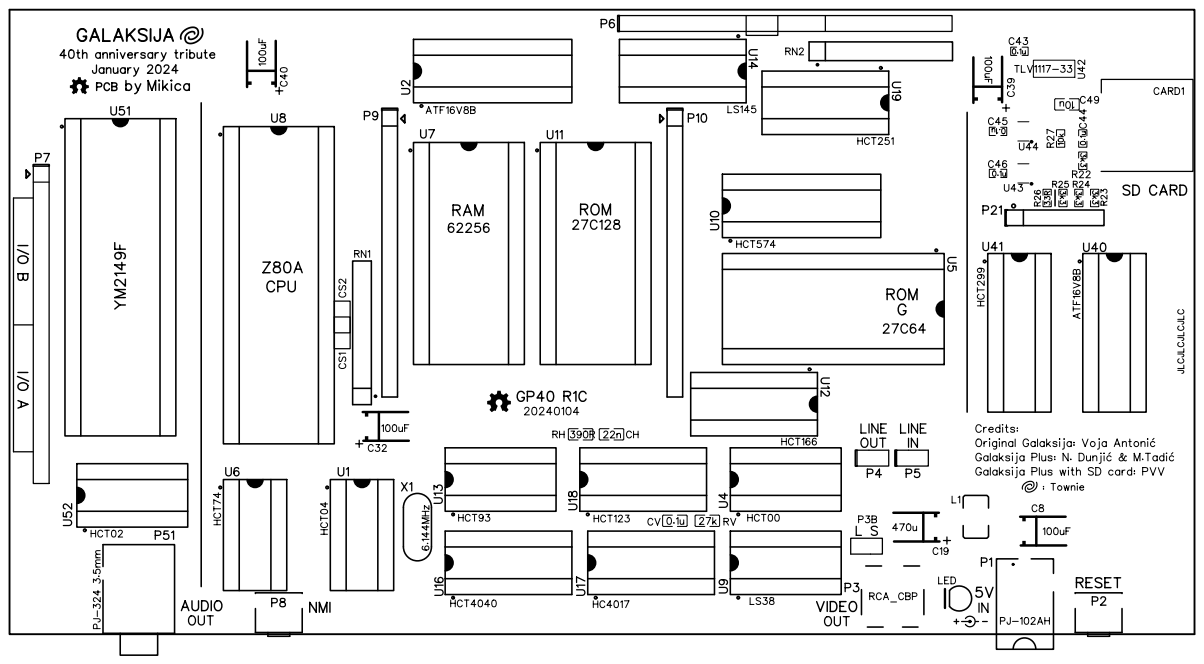
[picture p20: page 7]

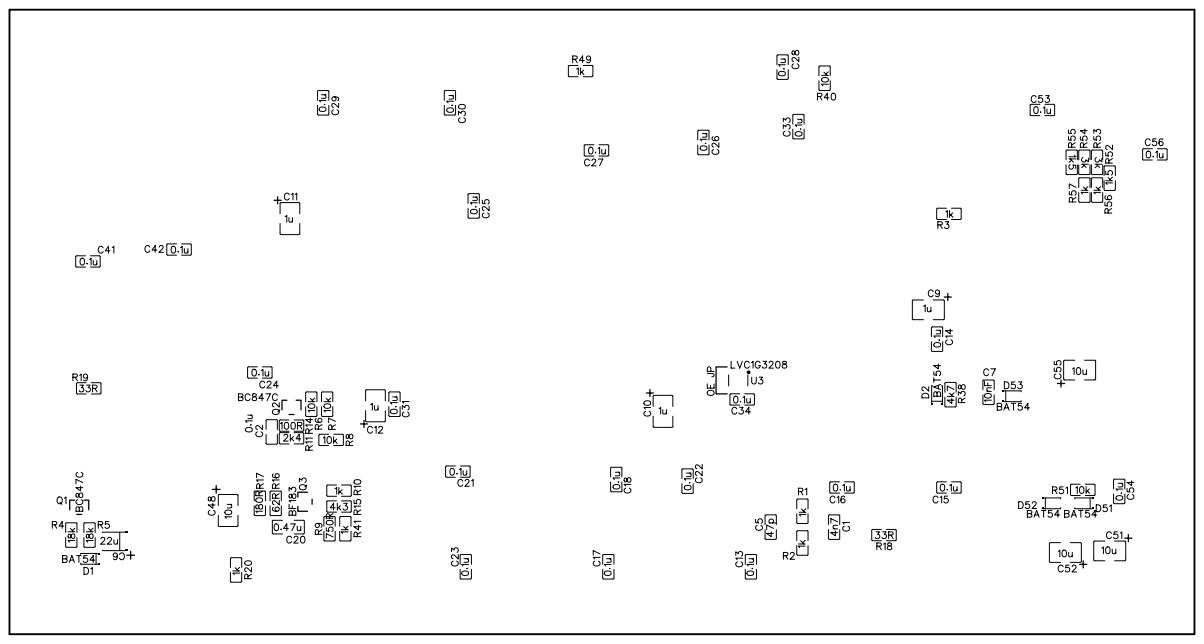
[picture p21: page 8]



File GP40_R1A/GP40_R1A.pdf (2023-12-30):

## SD card interface

## Audio Interface

TITLE:; GALAKSIJA 40th Anniversary Tribute; REV:; Date:; Sheet:; Drawn By:; mikica; Company:; Umuntu ngumuntu ngabantu; CPU Clock Video Timing; Sheet 1; Sheet 2; Sheet 3; Tape interface

CPU + ROM + RAM
Reset, NMI reset
Expansion bus

Keyboard and latch

Video ROM, shift out
register and output

Based on PVV's Galaksija Plus clone from 2017. Mods:
- integrated audio interface
- address decoder with ATF16V8B
- integrated micro SD socket with level shifters
- NMI reset circuit
- hybrid TH/SMD PCB (SMD discrete components on the bottom side)
- keyboard stackable on the back side (100x300mm)

Works with the following Galaksija Plus ROM images by PVV:
- GALAXY_ROM16_v8_6.BIN (16k), alt. GALAXY_v8_6.BIN (64k)
- GALAXY_CHGRGENP.BIN (8k), alt. GALAXY _CHRGEN.BIN (64k)
Hardware memory map:
$0000...$0FFF ROM "A" or "1" – 4 KB contains bootstrap
$1000...$1FFF ROM "B" or "2" – 4 KB (optional)
$2000...$27FF Keyboard and latch
$2800...$BFFF RAM: 30 KB ($2800...$2BFF Video RAM)
$C000...$C7FF RAM: 2 KB (SDOS)
$C800...$CFFF SD interface
$D000...$DFFF Unused, reserved
$E000...$FFFF ROM "3" + "4": 8 KB (Graphics, SDOS etc)

Credits:
- Voja Antonic: Galaksija (1983)
- Nenad Dunjic and Milan Tadic: Galaksija Plus mod (1985)
- PVV and Fifan: Galaksija Plus clone with SD card (2017)
- Goran Stankovic (YT2FSG): Retro Computers web page
- Retro Bertie (@MacBerti28): YouTube guide

Soldering sequence:
1. start with the SMD components on the bottom side
(the SMD components are 0805+ and easy to solder)
2. solder the SMD components on the top side
3. mount the IC sockets
4. mount the rest of the components

# Q12 1 Q11 15 Q10 14 Q9 12 Q8 13 Q7 4 Q6 2 Q5 3 Q4 5 Q3 6 Q2 7 Q1 9


\WR 22 \RD 21 \IORQ 20 \MREQ 19 \M1 27

Credits:
Original Galaksija: Voja Antonic
Galaksija Plus: N. Dunjic, M.Tadic
Galaksija Plus with SD card: PVV


References:
- GalaksijaPlus_PVV_GAL_NEW6_SD.pdf (2017-12-21)
- GalaksijaPlus_Fifan_Schematic.pdf (2019-02-21)
Found on:
http://www.nedopc.org/forum/viewtopic.php?p=87313
https://drive.google.com/drive/folders/1J3synVV-5PiKcZs9oFsY-6CqWDRKv7X2

P21 is connected to an external micro SD card reader,
for example: https://www.electrokit.com/produkt/microsd-lasare-3-3-5v/
(this is cheaper than to buy and solder U15, U3 and CARD1)

A built-in micro SD card reader with level shifters and 3.3V PS (optional)


\SEL has an internal pull-up
so it can be left unconnected.

Pin 23 of U51 is connected to \NMS.





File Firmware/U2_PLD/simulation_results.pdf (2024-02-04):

Signal; MREQ; ROM; RAM; CSE; KEY; CSSD

C:\Work\easyeda-data\galaksija\GAL16V8\GP_U2.SI

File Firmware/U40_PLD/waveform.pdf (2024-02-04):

Signal; CLK; CLK2; RUN; !RESET; SD_SCK

C:\WINCUPL\GALAKSIJA\GP40_U40\GP40_U40.SI

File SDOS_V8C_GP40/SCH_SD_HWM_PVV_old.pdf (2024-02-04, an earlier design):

+5V

### Цепь


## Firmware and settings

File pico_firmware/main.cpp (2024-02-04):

/* Galaksija USB Keyboard Interface
 *
 * The original Galaksija keyboard layout (similar to TRS-80 Model I):
 *
 *     .-----.-----.-----.-----.-----.-----.-----.-----.-----.-----.-----.-----.-----.
 *     |  !  |  "  |  #  |  $  |  %  |  &  |  '  |  (  |  )  |     |  *  |  -  |     |
 *     |  1  |  2  |  3  |  4  |  5  |  6  |  7  |  8  |  9  |  0  |  :  |  =  | brk |
 * .---'-.---'-.---'-.---'-.---'-.---'-.---'-.---'-.---'-.---'-.---'-.---'-.---'-.---'-.
 * |     |     |     |     |     |     |     |     |     |     |     |     |     |     |
 * | up  |  Q  |  W  |  E  |  R  |  T  |  Y  |  U  |  I  |  O  |  P  |left |right| del |
 * '-.---'-.---'-.---'-.---'-.---'-.---'-.---'-.---'-.---'-.---'-.---'-.---'-----'-.---'-.
 *   |     |     |     |     |     |     |     |     |     |     |  +  |           |stop |
 *   |down |  A  |  S  |  D  |  F  |  G  |  H  |  J  |  K  |  L  |  ;  |    ret    |list |
 *   '-.---'-.---'-.---'-.---'-.---'-.---'-.---'-.---'-.---'-.---'-.---'-.-----.---'-.---'
 *    |     |     |     |     |     |     |     |     |  <  |  >  |  ?  |     |     |
 *    |shift|  Z  |  X  |  C  |  V  |  B  |  N  |  M  |  ,  |  .  |  /  |rpt  |shift|
 *    '-----'-----'-----'-----'-----'-----'-----'-----'-----'-----'-----'-----'-----'
 *
 * The scan matrix (KC scan -> KR response):
 *
 *        KC=0       KC=1      KC=2      KC=3         KC=4      KC=5      KC=6
 * ----- ---------- --------- --------- ------------ --------- --------- -------------
 * KR=0  {0,1,NULL} {1,0,"H"} {2,0,"P"} {3,0,"X"   } {4,0,"0"} {5,0,"8"} {6,0,"ret"  }
 * KR=1  {0,1,"A" } {1,1,"I"} {2,1,"Q"} {3,1,"Y"   } {4,1,"1"} {5,1,"9"} {6,1,"brk"  }
 * KR=2  {0,2,"B" } {1,2,"J"} {2,2,"R"} {3,2,"Z"   } {4,2,"2"} {5,2,";"} {6,2,"rpt"  }
 * KR=3  {0,3,"C" } {1,3,"K"} {2,3,"S"} {3,3,"up"  } {4,3,"3"} {5,3,":"} {6,3,"del"  }
 * KR=4  {0,4,"D" } {1,4,"L"} {2,4,"T"} {3,4,"down"} {4,4,"4"} {5,4,","} {6,4,"list" }
 * KR=5  {0,4,"E" } {1,5,"M"} {2,5,"U"} {3,5,"left"} {4,5,"5"} {5,5,"="} {6,5,"shift"}
 * KR=6  {0,4,"F" } {1,6,"N"} {2,6,"V"} {3,6,"rght"} {4,6,"6"} {5,6,"."} {6,6,NULL   }
 * KR=7  {0,4,"G" } {1,7,"O"} {2,7,"w"} {3,7,"sp"  } {4,7,"7"} {5,7,"/"} {6,7,NULL   }
 *
 * Key bindings of the non-standard keys:
 *
 *  ESCAPE      -> brk
 *  DELETE      -> del
 *  INSERT      -> rpt
 *  APPLICATION -> list
 *  BACKSPACE   -> left
 *
 * The US keyboard layout:
 * .-----.-----.-----.-----.-----.-----.-----.-----.-----.-----.-----.-----.-----.--------.
 * |  ~  |  !  |  @  |  #  |  $  |  %  |  ^  |  &  |  *  |  (  |  )  |  _  |  +  |        |
 * |  `  |  1  |  2  |  3  |  4  |  5  |  6  |  7  |  8  |  9  |  0  |  -  |  =  | BSP    |
 * +-----'-----'-----'-----'-----'-----'-----'-----'-----'-----'-----'-----'-----'--------+
 * |       |     |     |     |     |     |     |     |     |     |     |  {  |  }  |  |   |
 * | TAB   |  Q  |  W  |  E  |  R  |  T  |  Y  |  U  |  I  |  O  |  P  |  [  |  ]  |  \   |
 * +---.---'-.---'-.---'-.---'-.---'-.---'-.---'-.---'-.---'-.---'-.---'-.---'-.---'------+
 * | CAPS    |     |     |     |     |     |     |     |     |     |  :  |  "  |          |
 * | LOCK    |  A  |  S  |  D  |  F  |  G  |  H  |  J  |  K  |  L  |  ;  |  '  |   ENTER  |
 * +---'-----'-.---'-.---'-.---'-.---'-.---'-.---'-.---'-.---'-.---'-.---'-.---'----------+
 * |           |     |     |     |     |     |     |     |  <  |  >  |  ?  |              |
 * | SHIFT     |  Z  |  X  |  C  |  V  |  B  |  N  |  M  |  ,  |  .  |  /  |    SHIFT     |
 * '-----------'-----'-----'-----'-----'-----'-----'-----'-----'-----'-----'--------------'
 */

#include <stdlib.h>
#include <stdio.h>

#include "pico/stdlib.h"
#include "pico/multicore.h"
#include "hardware/clocks.h"
#include "hardware/vreg.h"

#include "bsp/board.h"
#include "tusb.h"

#ifdef DEBUG
  #define debugf(...) printf(__VA_ARGS__)
#else
  #define debugf(...) 
#endif

///////////////////////////////////////////////////////////////////////////////
// KCKR hardware configuration

enum // GPIO0..GPIO15
{
  //
  // Column scan, inputs, pull-up enabled.
  // KC6-KC0 are connected to GPIO9-GPIO15.
  // Expected behavior:
  // - all KCs are pulled high by efault
  // - only one KC is pulled low during the keyboard scan
  //
  KC6 = 0,
  KC5 = 1,
  KC4 = 2,
  KC3 = 3,
  KC2 = 4,
  KC1 = 5,
  KC0 = 6,
  //
  // GPIO7 is an output that controls hardware reset of Galaksija.
  //
  GAL_RESET = 7,
  //
  // Row response, outputs.
  // KR7-KR0 are connected to GPIO0-GPIO7 (NOTE THE REVERSED BIT ORDER).
  //
  KR0 = 8,
  KR1 = 9,
  KR2 = 10,
  KR3 = 11,
  KR4 = 12,
  KR5 = 13,
  KR6 = 14,
  KR7 = 15
};

///////////////////////////////////////////////////////////////////////////////

// Map KC -> KR (note that KC is 7-bits wide)
volatile uint8_t scan_response[128] = { 0 };

static inline uint32_t get_KC ()
{
  // REVERSED ORDER: GPIO0 = KC6, GPIO1 = KC5, ...
  return gpio_get_all () & 0x7F;
}

static inline void put_KR( uint kc )
{
  // GPIO8 = KR0, GPIO9 = KR1, ...
  gpio_put_masked( /* mask */ 0xFF00, /* value */ scan_response[kc] << 8 );
}

// Keyboard scan response thread (running on the second core)
//
void KCKR_scan_response_thread ()
{
  for(;;)
  {
      put_KR( get_KC () );
  }
}

void KCKR_clear_scan_response ()
{
  for( uint i = 0; i < 128; ++i ) {
    scan_response[i] = 0x00;
  }
}

void KCKR_init ()
{
  KCKR_clear_scan_response ();

  // Set all output (GPIO7-GPIO15) to low
  //
  gpio_put_masked( /* mask */ 0xFF80, /* value */ 0x0000 );

  // Keyboard column scan
  //
  gpio_init( KC0 ); gpio_set_dir( KC0, GPIO_IN ); gpio_set_pulls( KC0, /*up*/true, /*down*/false );
  gpio_init( KC1 ); gpio_set_dir( KC1, GPIO_IN ); gpio_set_pulls( KC1, /*up*/true, /*down*/false );
  gpio_init( KC2 ); gpio_set_dir( KC2, GPIO_IN ); gpio_set_pulls( KC2, /*up*/true, /*down*/false );
  gpio_init( KC3 ); gpio_set_dir( KC3, GPIO_IN ); gpio_set_pulls( KC3, /*up*/true, /*down*/false );
  gpio_init( KC4 ); gpio_set_dir( KC4, GPIO_IN ); gpio_set_pulls( KC4, /*up*/true, /*down*/false );
  gpio_init( KC5 ); gpio_set_dir( KC5, GPIO_IN ); gpio_set_pulls( KC5, /*up*/true, /*down*/false );
  gpio_init( KC6 ); gpio_set_dir( KC6, GPIO_IN ); gpio_set_pulls( KC6, /*up*/true, /*down*/false );

  // Keyboard row response
  //
  gpio_init( KR0 ); gpio_set_dir( KR0, GPIO_OUT );
  gpio_init( KR1 ); gpio_set_dir( KR1, GPIO_OUT );
  gpio_init( KR2 ); gpio_set_dir( KR2, GPIO_OUT );
  gpio_init( KR3 ); gpio_set_dir( KR3, GPIO_OUT );
  gpio_init( KR4 ); gpio_set_dir( KR4, GPIO_OUT );
  gpio_init( KR5 ); gpio_set_dir( KR5, GPIO_OUT );
  gpio_init( KR6 ); gpio_set_dir( KR6, GPIO_OUT );
  gpio_init( KR7 ); gpio_set_dir( KR7, GPIO_OUT );

  // Galaksija reset
  //
  gpio_init( GAL_RESET ); gpio_set_dir( GAL_RESET, GPIO_OUT );

  // Set all output (GPIO8-GPIO0) to low
  //
  gpio_put_masked( /* mask */ 0xFF80, /* value */ 0x0000 );
}

///////////////////////////////////////////////////////////////////////////////
// Keyboard map

struct keycode_map {
  int kc;
  int kr;
  const char* name;
};

keycode_map keycode_to_KCKR[] =
{
//  KC  KR  NAME                       KEYCODE
// --- ---  ------- ----- --------------------
  { -1, -1, NULL    }, // (reserved)      0x00
  { -1, -1, NULL    }, // (reserved)      0x01
  { -1, -1, NULL    }, // (reserved)      0x02
  { -1, -1, NULL    }, // (reserved)      0x03
  {  0,  1, "A"     }, // A               0x04
  {  0,  2, "B"     }, // B               0x05
  {  0,  3, "C"     }, // C               0x06
  {  0,  4, "D"     }, // D               0x07
  {  0,  5, "E"     }, // E               0x08
  {  0,  6, "F"     }, // F               0x09
  {  0,  7, "G"     }, // G               0x0a
  {  1,  0, "H"     }, // H               0x0b
  {  1,  1, "I"     }, // I               0x0c
  {  1,  2, "J"     }, // J               0x0d
  {  1,  3, "K"     }, // K               0x0e
  {  1,  4, "L"     }, // L               0x0f
  {  1,  5, "M"     }, // M               0x10
  {  1,  6, "N"     }, // N               0x11
  {  1,  7, "O"     }, // O               0x12
  {  2,  0, "P"     }, // P               0x13
  {  2,  1, "Q"     }, // Q               0x14
  {  2,  2, "R"     }, // R               0x15
  {  2,  3, "S"     }, // S               0x16
  {  2,  4, "T"     }, // T               0x17
  {  2,  5, "U"     }, // U               0x18
  {  2,  6, "V"     }, // V               0x19
  {  2,  7, "W"     }, // W               0x1a
  {  3,  0, "X"     }, // X               0x1b
  {  3,  1, "Y"     }, // Y               0x1c
  {  3,  2, "Z"     }, // Z               0x1d
  {  4,  1, "1"     }, // 1               0x1e
  {  4,  2, "2"     }, // 2               0x1f
  {  4,  3, "3"     }, // 3               0x20
  {  4,  4, "4"     }, // 4               0x21
  {  4,  5, "5"     }, // 5               0x22
  {  4,  6, "6"     }, // 6               0x23
  {  4,  7, "7"     }, // 7               0x24
  {  5,  0, "8"     }, // 8               0x25
  {  5,  1, "9"     }, // 9               0x26
  {  4,  0, "0"     }, // 0               0x27
  {  6,  0, "ret"   }, // ENTER           0x28
  {  6,  1, "brk"   }, // ESCAPE          0x29
  {  3,  5, "left"  }, // BACKSPACE       0x2a
  {  3,  3, "up"    }, // TAB             0x2b
  {  3,  7, "sp"    }, // SPACE           0x2c
  { -1, -1, NULL    }, // MINUS           0x2d
  {  5,  5, "="     }, // EQUAL           0x2e
  {  3,  5, "left"  }, // BRACKET_LEFT    0x2f
  {  3,  6, "right" }, // BRACKET_RIGHT   0x30
  { -1, -1, NULL    }, // BACKSLASH       0x31
  { -1, -1, NULL    }, // EUROPE_1        0x32
  {  5,  2, ";"     }, // SEMICOLON       0x33
  {  5,  3, ":"     }, // APOSTROPHE      0x34
  { -1, -1, NULL    }, // GRAVE           0x35
  {  5,  4, ","     }, // COMMA           0x36
  {  5,  6, "."     }, // PERIOD          0x37
  {  5,  7, "/"     }, // SLASH           0x38
  {  3,  4, "down"  }, // CAPS_LOCK       0x39
  { -1, -1, NULL    }, // F1              0x3a
  { -1, -1, NULL    }, // F2              0x3b
  { -1, -1, NULL    }, // F3              0x3c
  { -1, -1, NULL    }, // F4              0x3d
  { -1, -1, NULL    }, // F5              0x3e
  { -1, -1, NULL    }, // F6              0x3f
  { -1, -1, NULL    }, // F7              0x40
  { -1, -1, NULL    }, // F8              0x41
  { -1, -1, NULL    }, // F9              0x42
  { -1, -1, NULL    }, // F10             0x43
  { -1, -1, NULL    }, // F11             0x44
  { -1, -1, NULL    }, // F12             0x45
  { -1, -1, NULL    }, // PRINT_SCREEN    0x46
  { -1, -1, NULL    }, // SCROLL_LOCK     0x47
  { -1, -1, NULL    }, // PAUSE           0x48
  { -1, -1, "rpt"   }, // INSERT          0x49
  { -1, -1, NULL    }, // HOME            0x4a
  { -1, -1, NULL    }, // PAGE_UP         0x4b
  {  6,  3, "del"   }, // DELETE          0x4c
  { -1, -1, NULL    }, // END             0x4d
  { -1, -1, NULL    }, // PAGE_DOWN       0x4e
  {  3,  6, "right" }, // ARROW_RIGHT     0x4f
  {  3,  5, "left"  }, // ARROW_LEFT      0x50
  {  3,  4, "down"  }, // ARROW_DOWN      0x51
  {  3,  3, "up"    }, // ARROW_UP        0x52
  { -1, -1, NULL    }, // NUM_LOCK        0x53
  { -1, -1, NULL    }, // KEYPAD_DIVIDE   0x54
  { -1, -1, NULL    }, // KEYPAD_MULTIPLY 0x55
  { -1, -1, NULL    }, // KEYPAD_SUBTRACT 0x56
  { -1, -1, NULL    }, // KEYPAD_ADD      0x57
  {  6,  0, "ret"   }, // KEYPAD_ENTER    0x58
  {  4,  1, "1"     }, // KEYPAD_1        0x59
  {  4,  2, "2"     }, // KEYPAD_2        0x5a
  {  4,  3, "3"     }, // KEYPAD_3        0x5b
  {  4,  4, "4"     }, // KEYPAD_4        0x5c
  {  4,  5, "5"     }, // KEYPAD_5        0x5d
  {  4,  6, "6"     }, // KEYPAD_6        0x5e
  {  4,  7, "7"     }, // KEYPAD_7        0x5f
  {  5,  0, "8"     }, // KEYPAD_8        0x60
  {  5,  1, "9"     }, // KEYPAD_9        0x61
  {  4,  0, "0"     }, // KEYPAD_0        0x62
  {  5,  6, "."     }, // KEYPAD_DECIMAL  0x63
  { -1, -1, NULL    }, // EUROPE_2        0x64
  {  6,  4, "list"  }, // APPLICATION     0x65
  { -1, -1, NULL    }, // POWER           0x66
  {  5,  5, "="     }, // KEYPAD_EQUAL    0x67
  // The regular keycodes stop at this point.
  // Below is an extension which incorporates SHIFT.
  {  6,  5, "SHIFT" }  // SHIFT           0x68
};

#define HID_KEY_MY_SHIFT 0x68

void KCKR_set( int keycode, bool on )
{
  debugf( "0x%02x %s", keycode, on ? "on " : "off" );

  if( keycode < 0 || keycode > HID_KEY_MY_SHIFT ) {
    debugf( "\n" );
    return;
  }

  const char* name = keycode_to_KCKR[keycode].name;
  int kc = 6 - keycode_to_KCKR[keycode].kc; // REVERSE ORDERED BITS
  int kr = keycode_to_KCKR[keycode].kr;

  if ( kc < 0 || kr < 0 || name == NULL ) {
    debugf( "\n" );
    return;
  }

  volatile uint8_t& state = scan_response[ ~( 1 << kc ) & 0x7F ];
  state = on ? state |  ( 1 << kr )
             : state & ~( 1 << kr );

  debugf( " -> %d, %d (%s)\n", 6 - kc, kr, name );
}

///////////////////////////////////////////////////////////////////////////////

struct Action {
  int keycode; // -1 = END, 0 = NOP (wait)
  bool on; // true = press, false = depress
  uint32_t interval_ms; // time to wait in this state
};

class MacroExecutor
{
  Action* action;
  int current = 0;
  uint32_t timeout_ms;

public:

  MacroExecutor( void )
  {
    action = NULL;
    current = -1;
    timeout_ms = 0;
  }

  bool is_idle( void )
  {
    return current < 0 || action == NULL || action[current].keycode < 0;
  }

  void start( Action* list )
  {
    action = list;
    current = 0;
    KCKR_set( action[current].keycode, action[current].on );
    timeout_ms = board_millis() + action[current].interval_ms;
  }

  void task()
  {
    if( is_idle() ) {
      return;
    }

    uint32_t current_ms = board_millis();
    if( current_ms >= timeout_ms )
    {
      // Current action expired. Proceed to the next step.
      ++current;
      if( action[current].keycode < 0 ) // End of macro
      {
        KCKR_clear_scan_response (); // clear all codes
        return;
      }

      KCKR_set( action[current].keycode, action[current].on );
      timeout_ms = current_ms + action[current].interval_ms;
    }
  }
};

///////////////////////////////////////////////////////////////////////////////

#define PRESS(key) \
  { key, true, 30 }, \
  { key, false, 30 }

#define PRESS_SHIFT(key) \
  { HID_KEY_MY_SHIFT, true, 0 }, \
  { key, true, 30 }, \
  { key, false, 30 }, \
  { HID_KEY_MY_SHIFT, false, 0 }

#define PRESS_END \
  { -1, false, 0 }

Action macro_USR_E000[] =
{
  PRESS( HID_KEY_A ),
  PRESS( HID_KEY_EQUAL ),
  PRESS( HID_KEY_U ),
  PRESS( HID_KEY_S ),
  PRESS( HID_KEY_R ),
  PRESS_SHIFT( HID_KEY_8 ), // "("
  PRESS_SHIFT( HID_KEY_6 ), // "&"
  PRESS( HID_KEY_E ),
  PRESS( HID_KEY_0 ),
  PRESS( HID_KEY_0 ),
  PRESS( HID_KEY_0 ),
  PRESS_SHIFT( HID_KEY_9 ), // ")"
  PRESS( HID_KEY_ENTER ),
  PRESS_END
};

Action macro_USR_F000[] =
{
  PRESS( HID_KEY_A ),
  PRESS( HID_KEY_EQUAL ),
  PRESS( HID_KEY_U ),
  PRESS( HID_KEY_S ),
  PRESS( HID_KEY_R ),
  PRESS_SHIFT( HID_KEY_8 ), // "("
  PRESS_SHIFT( HID_KEY_6 ), // "&"
  PRESS( HID_KEY_F ),
  PRESS( HID_KEY_0 ),
  PRESS( HID_KEY_0 ),
  PRESS( HID_KEY_0 ),
  PRESS_SHIFT( HID_KEY_9 ), // ")"
  PRESS( HID_KEY_ENTER ),
  PRESS_END
};

Action macro_DIR[] =
{
  PRESS( HID_KEY_D ),
  PRESS( HID_KEY_I ),
  PRESS( HID_KEY_R ),
  PRESS( HID_KEY_ENTER ),
  PRESS_END
};

Action macro_RUN[] =
{
  PRESS( HID_KEY_R ),
  PRESS( HID_KEY_U ),
  PRESS( HID_KEY_N ),
  PRESS( HID_KEY_ENTER ),
  PRESS_END
};

///////////////////////////////////////////////////////////////////////////////

MacroExecutor macroExecutor;

int main( void )
{
  // The KC/KR response time is below 200 ns at 125 MHz.
  // If the system clock speed is 240 MHz, it drops to 100 ns.
  // vreg_set_voltage( VREG_VOLTAGE_1_20 );
  // set_sys_clock_khz( 240000, true );

  board_init ();
  KCKR_init ();
  printf( "Galaksija Keyboard v0.5\n" );

  // Init host stack on configured roothub port
  tuh_init( BOARD_TUH_RHPORT );

  // Start the KC/KR scan response thread on core1
  multicore_launch_core1( KCKR_scan_response_thread );

  for( ;; )
  {
    tuh_task ();
    macroExecutor.task ();

    // Blink LED every interval_ms
    //
    static bool led_state = true;
    static uint32_t start_ms = 0;
    const uint32_t interval_ms1 = 100;
    const uint32_t interval_ms2 = 2000;
    if( led_state )
    {
      if( board_millis() >= start_ms + interval_ms2 )
      {
        start_ms += interval_ms2;
        board_led_write( led_state );
        led_state = ! led_state;
      }
    }
    else
    {
      if( board_millis() >= start_ms + interval_ms1 )
      {
        start_ms += interval_ms1;
        board_led_write( led_state );
        led_state = ! led_state;
      }
    }
  }
}

///////////////////////////////////////////////////////////////////////////////
// TinyUSB Callbacks

void tuh_mount_cb( uint8_t dev_addr ) // Application set-up
{
  printf( "Mounted %d\n", dev_addr );
}

void tuh_umount_cb( uint8_t dev_addr ) // Application tear-down
{
  printf( "Unmounted %d\n", dev_addr );
}

///////////////////////////////////////////////////////////////////////////////
// Each HID instance can has multiple reports

#define MAX_REPORT  4

static struct
{
  uint8_t report_count;
  tuh_hid_report_info_t report_info[MAX_REPORT];
} hid_info[CFG_TUH_HID];

static void process_kbd_report( hid_keyboard_report_t const *report);
static void process_mouse_report( hid_mouse_report_t const * report);
static void process_generic_report( uint8_t dev_addr, uint8_t instance, uint8_t const* report, uint16_t len);

///////////////////////////////////////////////////////////////////////////////
// TinyUSB Callbacks
///////////////////////////////////////////////////////////////////////////////

///////////////////////////////////////////////////////////////////////////////
// tuh_hid_mount_cb is invoked when device with hid interface is mounted.
// Report descriptor is also available for use. tuh_hid_parse_report_descriptor()
// can be used to parse common/simple enough descriptor.
// Note: if report descriptor length > CFG_TUH_ENUMERATION_BUFSIZE, it will be skipped
// therefore report_desc = NULL, desc_len = 0.
//
void tuh_hid_mount_cb(
  uint8_t dev_addr, uint8_t instance,
  uint8_t const* desc_report, uint16_t desc_len
  )
{
  printf( "HID device address = %d, instance = %d is mounted\n", dev_addr, instance );

  // Interface protocol (hid_interface_protocol_enum_t)
  const char* protocol_str[] = { "None", "Keyboard", "Mouse" };
  uint8_t const itf_protocol = tuh_hid_interface_protocol(dev_addr, instance);

  printf( "HID Interface Protocol = %s\n", protocol_str[itf_protocol] );

  // By default host stack will use activate boot protocol on supported interface.
  // Therefore for this simple example, we only need to parse generic report descriptor (with built-in parser)
  if ( itf_protocol == HID_ITF_PROTOCOL_NONE )
  {
    hid_info[instance].report_count = tuh_hid_parse_report_descriptor(hid_info[instance].report_info, MAX_REPORT, desc_report, desc_len);
    printf( "HID has %u reports\n", hid_info[instance].report_count );
  }

  // request to receive report
  // tuh_hid_report_received_cb() will be invoked when report is available
  if ( !tuh_hid_receive_report(dev_addr, instance) )
  {
    printf( "Error: cannot request to receive report\n" );
  }
}

///////////////////////////////////////////////////////////////////////////////
// Invoked when device with hid interface is un-mounted
//
void tuh_hid_umount_cb( uint8_t dev_addr, uint8_t instance )
{
  printf( "HID device address = %d, instance = %d is unmounted\n", dev_addr, instance );
}

///////////////////////////////////////////////////////////////////////////////
// Invoked when received report from device via interrupt endpoint
//
void tuh_hid_report_received_cb(
  uint8_t dev_addr, uint8_t instance,
  uint8_t const* report, uint16_t len
  )
{
  uint8_t const itf_protocol = tuh_hid_interface_protocol(dev_addr, instance);

  switch (itf_protocol)
  {
    case HID_ITF_PROTOCOL_KEYBOARD:
      TU_LOG2("HID receive boot keyboard report\n");
      process_kbd_report( (hid_keyboard_report_t const*) report );
    break;

    case HID_ITF_PROTOCOL_MOUSE:
      TU_LOG2("HID receive boot mouse report\n");
      process_mouse_report( (hid_mouse_report_t const*) report );
    break;

    default:
      // Generic report requires matching ReportID and contents with previous parsed report info
      process_generic_report(dev_addr, instance, report, len);
    break;
  }

  // continue to request to receive report
  if ( !tuh_hid_receive_report(dev_addr, instance) )
  {
    printf( "Error: cannot request to receive report\n" );
  }
}

///////////////////////////////////////////////////////////////////////////////
// Look up new key in previous keys
//

// Previous report to check key released
//
static hid_keyboard_report_t prev_report = { 0, 0, {0} };

static inline bool find_key_in_report( hid_keyboard_report_t const* report, uint8_t keycode )
{
  for( int i = 0; i < 6; ++i )
  {
    if( report->keycode[i] == keycode ) {
      return true;
    }
  }

  return false;
}
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

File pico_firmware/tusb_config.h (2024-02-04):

/* 
 * The MIT License (MIT)
 *
 * Copyright (c) 2019 Ha Thach (tinyusb.org)
 *
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
 */

#ifndef _TUSB_CONFIG_H_
#define _TUSB_CONFIG_H_

#ifdef __cplusplus
 extern "C" {
#endif

//--------------------------------------------------------------------+
// Board Specific Configuration
//--------------------------------------------------------------------+

#if CFG_TUSB_MCU == OPT_MCU_RP2040
// change to 1 if using pico-pio-usb as host controller for raspberry rp2040
#define CFG_TUH_RPI_PIO_USB   0
#define BOARD_TUH_RHPORT      CFG_TUH_RPI_PIO_USB
#endif

// RHPort number used for host can be defined by board.mk, default to port 0
#ifndef BOARD_TUH_RHPORT
#define BOARD_TUH_RHPORT      0
#endif

// RHPort max operational speed can defined by board.mk
#ifndef BOARD_TUH_MAX_SPEED
#define BOARD_TUH_MAX_SPEED   OPT_MODE_DEFAULT_SPEED
#endif

//--------------------------------------------------------------------
// COMMON CONFIGURATION
//--------------------------------------------------------------------

// defined by compiler flags for flexibility
#ifndef CFG_TUSB_MCU
#error CFG_TUSB_MCU must be defined
#endif

#ifndef CFG_TUSB_OS
#define CFG_TUSB_OS           OPT_OS_NONE
#endif

#ifndef CFG_TUSB_DEBUG
#define CFG_TUSB_DEBUG        0
#endif

// Enable Host stack
#define CFG_TUH_ENABLED       1

// Default is max speed that hardware controller could support with on-chip PHY
#define CFG_TUH_MAX_SPEED     BOARD_TUH_MAX_SPEED

/* USB DMA on some MCUs can only access a specific SRAM region with restriction on alignment.
 * Tinyusb use follows macros to declare transferring memory so that they can be put
 * into those specific section.
 * e.g
 * - CFG_TUSB_MEM SECTION : __attribute__ (( section(".usb_ram") ))
 * - CFG_TUSB_MEM_ALIGN   : __attribute__ ((aligned(4)))
 */
#ifndef CFG_TUSB_MEM_SECTION
#define CFG_TUSB_MEM_SECTION
#endif

#ifndef CFG_TUSB_MEM_ALIGN
#define CFG_TUSB_MEM_ALIGN          __attribute__ ((aligned(4)))
#endif

//--------------------------------------------------------------------
// CONFIGURATION
//--------------------------------------------------------------------

// Size of buffer to hold descriptors and other data used for enumeration
#define CFG_TUH_ENUMERATION_BUFSIZE 256

#define CFG_TUH_HUB                 1 // number of supported hubs
#define CFG_TUH_CDC                 0
#define CFG_TUH_HID                 4 // typical keyboard + mouse device can have 3-4 HID interfaces
#define CFG_TUH_MSC                 0
#define CFG_TUH_VENDOR              0

// max device support (excluding hub device)
#define CFG_TUH_DEVICE_MAX          (CFG_TUH_HUB ? 4 : 1) // hub typically has 4 ports

//------------- HID -------------//
#define CFG_TUH_HID_EPIN_BUFSIZE    64
#define CFG_TUH_HID_EPOUT_BUFSIZE   64

#ifdef __cplusplus
 }
#endif

#endif /* _TUSB_CONFIG_H_ */

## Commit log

2023-12-30 PCB R1A
    [BOM.csv]
2024-01-04 PCB R1C
    [BOM.csv]
2024-02-04 PCB R1D
    [BOM.csv]
2024-02-04 Added Gerbers
    [Drill_NPTH_Through.DRL, Drill_PTH_Through.DRL, Drill_PTH_Through_Via.DRL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]
2024-02-04 Added mechanical keyboard
    [Drill_NPTH_Through.DRL, Drill_PTH_Through.DRL, Drill_PTH_Through_Via.DRL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]
2024-02-04 Added PS2 Keyboard
    [Drill_PTH_Through.DRL, Drill_PTH_Through_Via.DRL, Gerber_BoardOutlineLayer.GKO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]
2024-02-04 Added Pico USB PCB and Firmware
    [BOM.csv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]
2024-02-05 Archived old pcb releases
    [BOM.csv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]
2024-02-06 Added tapes
    [01 Asteroidi.gtp, 02 Bilijar.gtp, 03 Bioritam 1.gtp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]
